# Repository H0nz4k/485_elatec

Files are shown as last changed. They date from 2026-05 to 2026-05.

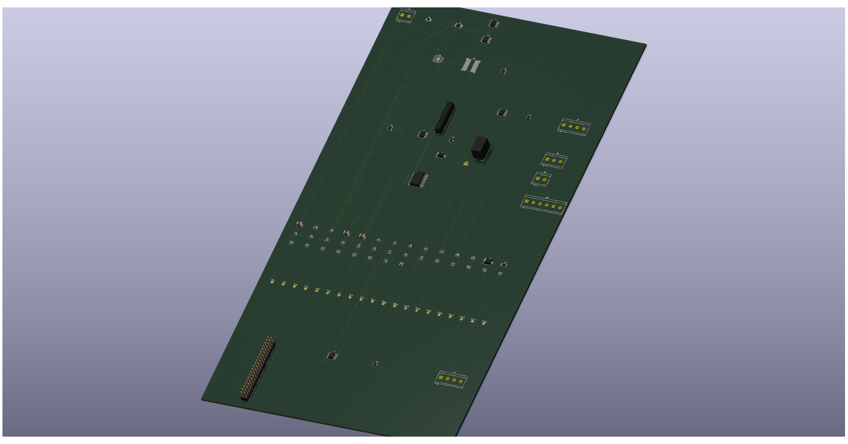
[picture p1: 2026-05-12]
kicad/twn4_access_system/twn4_access_system_rev_c.png

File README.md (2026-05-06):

# 485_elatec

Hardware concept for an ELATEC TWN4 MultiTech 3 BLE carrier board with RS-485 / OSDP, wide-range DC input, door lock outputs, and a Raspberry Pi-side RS-485 gateway.

## Current contents

- `analyza_twn4_carrier.md` - design analysis and architecture notes
- `schema_twn4_carrier_rev_a.md` - first schematic-level design proposal
- `rpi_gateway_hw.md` - Raspberry Pi RS-485 gateway / HAT notes
- `kicad/twn4_access_system/` - KiCad concept schematic for the reader carrier and RPi gateway

The design is currently Rev A concept-level work. It still needs component selection, footprint assignment, detailed ERC review, PCB layout, and bench validation before hardware production.

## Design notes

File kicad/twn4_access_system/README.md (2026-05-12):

# KiCad: TWN4 access system

This is a concept KiCad project for two related hardware blocks:

- reader-side TWN4 carrier / door module
- Raspberry Pi-side RS-485 gateway / HAT

The project contains two schematic sheets:

- `twn4_access_system.kicad_sch` - Rev A concept drawing
- `twn4_access_system_rev_b.kicad_sch` - Rev B schematic draft with concrete symbols, named nets, candidate footprints, and both reader-side and Raspberry Pi-side hardware

The Rev B electrical design notes and preliminary BOM are documented in:

- `../../schema_electrical_rev_b.md`
- `../../bom_rev_b.csv`

Current Rev B KiCad status:

- netlist export works and contains the real schematic components/nets
- Rev B now includes explicit service-prototype passives, RS-485 termination/bias options, lock/relay/input support parts and testpoints
- ERC has no error-severity findings after the current pass
- remaining ERC messages are warnings from embedded one-off symbols and intentionally single-ended configuration nets
- no Rev B PCB has been validated yet

Next KiCad step: replace the embedded placeholder-style symbols with proper library symbols/aliases, lock exact manufacturer footprints, then create the first service PCB layout.

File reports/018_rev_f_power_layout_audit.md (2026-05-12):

# Report 018 - Rev F power layout audit

## What changed

- Created Rev F branch and KiCad files from the Rev E routed checkpoint:
  - `kicad/twn4_access_system/twn4_access_system_rev_f.kicad_sch`
  - `kicad/twn4_access_system/twn4_access_system_rev_f_compact_power_cleanup.kicad_pcb`
- Added Rev F title block metadata and an F.Fab audit note:
  - `REV F AUDIT CHECKPOINT - MANUAL BUCK/LOCK REROUTE REQUIRED`
- Generated Rev F manufacturing draft outputs:
  - `manufacturing/rev_f/gerbers`
  - `manufacturing/rev_f/drill`
  - `manufacturing/rev_f/bom`
  - `manufacturing/rev_f/pick_place`
  - `manufacturing/rev_f/jlcpcb_upload_draft`
- Ran DRC after restoring the DRC-clean Rev E routing baseline with Rev F metadata.

## Why it changed

Rev E was DRC clean, but the critical power nets were still routed with autorouter-style 0.20 mm tracks. Rev F started the power-layout cleanup by testing whether the existing autorouted topology could safely support wider power traces.

## Attempted cleanup

Two widening attempts were tested and rejected:

- aggressive pass:
  - VIN nets: 0.60 mm
  - LOCK_SW_LOW: 0.80 mm
  - +5V: 0.40 mm
  - SW_NODE: 0.60 mm
  - result: 152 DRC violations
- conservative pass:
  - VIN_PROT/+5V/SW_NODE: 0.25 mm
  - result: 38 DRC violations

The violations were mostly clearance errors and some actual shorting-item reports where widened tracks crossed too close to unrelated autorouted logic traces.

## Engineering conclusion

ASSUMPTION: The existing Rev E routing is acceptable as a connectivity proof, but it is not a safe basis for simply widening traces.

The correct Rev F power cleanup is a manual reroute of the buck and lock/relay sections:

- place and route the buck loop as a local power island,
- keep the switching node compact,
- keep feedback away from noisy nodes,
- route lock current paths as short, wide, intentional copper,
- keep relay coil and lock switch paths separated,
- preserve 0.20 mm or larger clearance after the wider copper is in place.

## Verification

Final Rev F checkpoint DRC:

- `reports/rev_f_power_cleanup_drc.rpt`
- 0 DRC violations
- 0 unconnected pads
- 0 footprint errors

## Remaining risks

- Buck layout still needs manual reroute before ordering.
- Lock/relay current paths still need manual reroute before ordering.
- Connector current rating and real lock current remain unverified.
- X2/standoff geometry still requires physical validation.
- Schematic Rev F is still derived from the broader Rev E/Rev B schematic and should be split into carrier-only and RPi-gateway sheets before production.

## Next step

Open the Rev F PCB in KiCad GUI and manually reroute only these blocks:

1. buck input/protection to U2,
2. U2/L1/C5/C6 5 V power loop,
3. lock connector J5 to D2/Q4/VIN_PROT/GND return,
4. relay K1/Q3/D5 coil path.

After manual reroute, rerun DRC and update manufacturing outputs.

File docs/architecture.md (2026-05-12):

# Architecture

## Rev B Prototype Blocks

1. TWN4 carrier interface
2. Protected 12-48 V input
3. 5 V buck supply for TWN4 and local logic
4. Optional/local 3.3 V logic rail
5. RS-485 / OSDP interface
6. Dry relay output
7. Powered lock output
8. Door/REX/tamper/AUX inputs
9. Raspberry Pi RS-485 gateway/HAT concept

## Communication

Primary wired communication for Rev B is OSDP over half-duplex RS-485.

BLE is intentionally not part of the first production prototype. It remains a future feature because the first board must validate power, COM1 polarity, RS-485 and door IO first.

## Service Prototype Philosophy

The first board should be easy to measure and rework:

- large testpoints,
- jumpers for RS-485 termination and bias,
- service disconnect for lock output,
- clearly labeled field terminals,
- conservative trace widths and clearances.

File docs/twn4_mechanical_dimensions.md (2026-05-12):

# TWN4 MultiTech 3 BLE Mechanical Notes

Source: `TWN4DevPack507.zip`, extracted document `_extracted_docs/TWN4 MultiTech 3 DocRev10.pdf`, sections 2.2 and 2.3.2.

## Extracted Dimensions

- Reader PCB envelope: 50.00 mm x 35.00 mm.
- Figure 2.3 top view also shows reference dimensions 12.50 mm, 10.00 mm, 16.50 mm, 11.20 mm, 20.00 mm, and 2.80 mm around component and mounting geometry.
- Figure 2.3 bottom view shows additional reference dimensions 22.80 mm, 8.00 mm, and USB connector offset 4.00 mm.
- X2 generic interface:
  - double row header/socket,
  - 2.00 mm pitch,
  - 2 x 12 positions,
  - example populated connector: Samtec `PTT-124-01-S-D`,
  - pin orientation shown in Figure 2.5, with pin 1/2 at one end and pin 23/24 at the opposite end.

## Rev D Layout Assumptions

- ASSUMPTION: The compact carrier should use the TWN4 50.00 mm x 35.00 mm body as the primary mechanical envelope.
- ASSUMPTION: The reader should plug into the carrier through X2; the carrier PCB may extend to one side/bottom for field wiring.
- ASSUMPTION: The RPi gateway electronics are not part of this compact reader carrier. They should become a separate PCB or separate schematic variant.
- ASSUMPTION: Current 5.08 mm terminal blocks are too large for a carrier only slightly bigger than the reader. Rev D keeps them as workflow placeholders, but a real compact layout should move to smaller pluggable connectors, likely 3.50 mm or 2.50/2.54 mm depending on current and installer ergonomics.

## Open Mechanical Risks

- The exact X2 pin-1 center coordinate relative to the 50 x 35 mm TWN4 body still needs physical confirmation against a real reader, a printed 1:1 drawing, or an original mechanical CAD/DXF if ELATEC provides one.
- Connector mating height is not yet fixed. A carrier socket/pin solution must be chosen before production.
- Mounting hole/standoff geometry is not yet implemented in PCB.
- Component height under the reader body is not validated. Keep tall components in the side/bottom extension unless the reader standoff height is known.

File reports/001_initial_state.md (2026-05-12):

# 001 Initial State

Date: 2026-05-07

## What Was Checked

- Workspace root: `C:\Work\projects\elatec-485`
- KiCad project: `kicad/twn4_access_system/twn4_access_system.kicad_pro`
- Rev A concept schematic: `kicad/twn4_access_system/twn4_access_system.kicad_sch`
- Rev B schematic draft: `kicad/twn4_access_system/twn4_access_system_rev_b.kicad_sch`
- Existing design notes: `schema_electrical_rev_b.md`, `bom_rev_b.csv`, `rpi_gateway_hw.md`
- KiCad CLI version: 9.0.7

## Toolchain State

- `git.exe` is not available in this local environment.
- The workspace is not a local git checkout; `.git` is missing.
- Required branch `feature/rev-b-jlcpcb-prototype` could not be created locally.

ASSUMPTION: work continues in this filesystem copy, and the resulting files will be copied or committed later from a real git clone.

## Current KiCad State

- Rev B schematic exports a KiCad netlist.
- Rev B schematic currently uses embedded one-off symbols for several project-specific parts.
- A local symbol library file was generated as `kicad/twn4_access_system/rev_b_symbols.kicad_sym`, but CLI netlist export was more reliable with embedded symbols, so the active schematic still uses embedded symbols for now.
- No routed PCB file exists yet for Rev B.

## Verification

- KiCad CLI is available.
- Rev B netlist export was run successfully after cleanup.
- ERC was run with KiCad CLI.

## Risks

- No git branch or commits can be made until the project is opened in a real git clone with git installed.
- Rev B is not ready for JLCPCB order because there is no validated PCB layout.
- Mechanical connector alignment for TWN4 X2 is not verified.

## Next Step

Continue with schematic cleanup, footprint checks, report generation, and prototype manufacturing documentation.

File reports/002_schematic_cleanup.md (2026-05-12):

# 002 Schematic Cleanup

Date: 2026-05-07

## What Changed

- Updated Rev B schematic footprint candidates where KiCad 9 had direct matching library footprints.
- Generated a local project symbol library: `kicad/twn4_access_system/rev_b_symbols.kicad_sym`.
- Generated a project symbol library table: `kicad/twn4_access_system/sym-lib-table`.
- Kept the active Rev B schematic on embedded symbols because KiCad CLI netlist export remained correct in that mode.
- Exported a KiCad BOM to `manufacturing/rev_b/bom/rev_b_kicad_bom.csv`.
- Added explicit service-prototype support parts: input capacitors, input TVS placeholder, LTC4367 divider placeholders, LM5164 feedback/RON/bootstrap/output parts, RS-485 termination/bias options, lock and relay gate/pulldown/flyback parts, input pull/filter parts and testpoints.

## Why

The previous Rev B schematic had usable named nets but was still a generated draft. The cleanup step makes it more reviewable and starts separating reusable project assets from one-off generation.

## Assumptions

- Embedded symbols are acceptable for the current prototype checkpoint because they preserve the full netlist.
- The local symbol library will be used in a later GUI cleanup pass or regenerated into a fully linked KiCad library once netlist behavior is confirmed.
- Footprints remain provisional until exact orderable manufacturer part numbers are locked.

## Verified

- Netlist export: OK
- Netlist component count: 82
- Net count: 53
- ERC errors: 0
- ERC warnings: 135

## Remaining ERC Warnings

The remaining warnings are not electrical pin-connect errors. They are mostly:

- embedded/project symbol library warnings,
- intentionally single-ended setup/configuration nets,
- intentionally DNP jumper/bias/termination options.

## Risks

- Some symbols are simplified functional symbols, not final manufacturer symbols.
- Some support values are still engineering placeholders and must be reviewed against final part numbers and measured current needs.
- A PCB generated from this exact schematic would still need a senior review before fabrication.

## Next Step

Add explicit support components and testpoints into the schematic, then create the first service-oriented PCB layout.

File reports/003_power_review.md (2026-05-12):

# 003 Power Review

Date: 2026-05-07

## Design Intent

Input range target: 12 V to 48 V nominal.

The Rev B concept uses:

- protected input rail `VIN_PROT`,
- 5 V buck rail for TWN4 and relay/logic support,
- optional/local 3.3 V rail for IO expansion if needed.

## Candidate Parts

- Input protection controller: LTC4367
- Buck regulator: LM5164
- 3.3 V LDO: TLV75533

## Source Checks

- TI LM5164 product page confirms 6 V to 100 V input capability and 1 A max output class: https://www.ti.com/product/LM5164
- Analog Devices LTC4367 product page confirms 2.5 V to 60 V operating range, overvoltage protection to 100 V, reverse supply protection, and control of back-to-back N-MOSFETs: https://www.analog.com/en/products/ltc4367.html

## Assumptions

- TWN4 plus local electronics stay below roughly 500 mA on 5 V in normal operation.
- Door lock power is not taken from the 5 V rail; it is switched from protected input voltage.
- First prototype is service/debug oriented, so efficiency and board size are secondary to robust measurement and rework.

## Schematic Additions Made

- Added input bulk/HF capacitors.
- Added input TVS placeholder.
- Added LTC4367 UV/OV divider placeholders.
- Added LM5164 RON, feedback divider, bootstrap capacitor, input capacitor and output capacitors.
- Added 3.3 V LDO input/output capacitors.
- Added power testpoints.

## Still Required

- Final input TVS part number for 48 V nominal environment.
- Final LTC4367 divider calculation.
- Final LM5164 values checked against the exact switching target and load.
- Thermal/current review after exact lock and reader current are known.

## Risks

- 48 V nominal systems can have transients above nominal; TVS selection must not clamp during normal operation but must protect downstream parts.
- LM5164 layout is critical. The high di/dt loop must be compact, with SW node kept small.
- Lock transients can inject noise into VIN_PROT if flyback/TVS placement is poor.

## Next Step

Add explicit power passives and testpoints before PCB layout.

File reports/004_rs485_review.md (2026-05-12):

# 004 RS-485 Review

Date: 2026-05-07

## Design Intent

Use RS-485 for OSDP as the first wired multi-reader path. BLE is deferred to a future revision.

## Candidate Parts

- Reader side transceiver: THVD1450
- RPi side transceiver: THVD1450
- RS-485 TVS: SM712

## Source Checks

- TI THVD1450 product page describes 3.3 V to 5 V RS-485 family with high IEC ESD protection: https://www.ti.com/product/THVD1450
- Bourns SM712 datasheet identifies the device as RS-485 port protection: https://www.bourns.com/docs/product-datasheets/cdsot23-sm712.pdf

## Assumptions

- OSDP is half-duplex RS-485.
- `DE` and `RE#` are tied to one direction-control signal for the first prototype.
- Bias and termination must be selectable so only the bus end is terminated/biased.

## Schematic Additions Made

- Added DNP 120 ohm termination option.
- Added DNP 680 ohm pull-up/pull-down bias options.
- Added A/B series resistor options.
- Added RS-485 and UART-related testpoints.

## Still Required

- Decide final jumper/DIP implementation for termination and bias.
- Verify A/B polarity on bench and silkscreen.
- Add PCB placement so TVS is physically close to field connector.

## Galvanic Isolation Decision

Recommendation for Rev B: do not add isolation yet unless field wiring length, ground potential differences, or external PSU topology demand it.

Reason: first prototype should validate TWN4 COM1 polarity, OSDP timing, bus bias/termination and power/lock behavior with fewer variables. Add isolation in Rev C after bench and site conditions are known.

## Risks

- A/B naming varies by vendor. The prototype must expose testpoints and clear silkscreen so polarity can be swapped or corrected if needed.
- TWN4 COM1 is documented as low-active TTL; polarity must be checked on an oscilloscope with firmware before final PCB release.

## Next Step

Make termination and bias explicit in schematic and PCB, with accessible jumpers.

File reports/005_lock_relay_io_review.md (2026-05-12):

# 005 Lock Relay IO Review

Date: 2026-05-07

## Design Intent

Rev B should support:

- dry relay contact for external door controller input,
- powered lock output from protected input rail,
- door/REX/tamper/AUX inputs for field wiring.

## Assumptions

- Lock current is unknown, so the first prototype must be conservative and serviceable.
- Powered lock output should be switchable from `VIN_PROT`, not from 5 V.
- Relay output is a dry contact only.

## Schematic Additions Made

- Added lock service link.
- Added lock gate resistor and pulldown.
- Added relay gate resistor and pulldown.
- Added relay flyback diode.
- Added input pull-up and RC filter placeholders.
- Added testpoints for lock, relay and inputs.

## Still Required

- Select final lock flyback/TVS strategy after lock type and current are known.
- Add explicit ESD/TVS input arrays near input connector.
- Confirm MOSFET current/thermal margin against target lock.

## Risks

- Door strikes and maglocks can have very different transient behavior.
- If the lock shares supply wiring with logic, poor return routing can reset TWN4 or corrupt RS-485.
- Long input cables need ESD and filtering close to the connector.

## Next Step

Promote these support parts from notes into real schematic components and keep the lock power path physically away from logic on PCB.

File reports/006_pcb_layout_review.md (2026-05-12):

# 006 PCB Layout Review

Date: 2026-05-07

## Current State

No Rev B PCB layout has been produced or validated yet.

## Layout Requirements

- Service prototype, not miniaturized.
- Large testpoints.
- Clear connector labels.
- Buck regulator placed and routed according to datasheet layout guidance.
- Input protection close to power connector.
- RS-485 TVS close to bus connector.
- Lock transient suppression close to lock connector.
- Logic and lock current returns controlled deliberately.
- Optional jumpers for RS-485 termination and bias.

## Manufacturing Assumptions

- JLCPCB standard 2-layer or 4-layer process can be used.
- For first prototype, 4-layer is preferred if cost is acceptable because it gives a cleaner ground reference for buck, RS-485 and logic.
- Use conservative clearances and trace widths, especially for VIN and lock current.

## Risks

- Mechanical X2 position is not locked.
- Connector height and standoff height are not locked.
- Current draw of selected lock is unknown.

## Next Step

Create the initial PCB only after schematic support components and footprints are explicit enough for DRC and BOM/CPL consistency.

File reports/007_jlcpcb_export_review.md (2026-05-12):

# 007 JLCPCB Export Review

Date: 2026-05-07

## Current State

The manufacturing directory exists, but it is not yet a complete order package.

Generated:

- `manufacturing/rev_b/bom/rev_b_kicad_bom.csv`

Not generated yet:

- Gerbers
- Drill files
- Pick and Place / CPL

## Reason

There is currently no validated Rev B PCB layout file. Generating manufacturing outputs without a reviewed PCB would create false confidence.

## JLCPCB Requirements To Satisfy

- Valid Gerber set.
- Valid drill files.
- BOM with exact manufacturer/orderable parts.
- CPL/Pick and Place matching footprints and reference designators.
- Assembly notes identifying hand-soldered parts.
- Known risks documented.

## Risks

- Candidate footprints are not the same as confirmed JLCPCB-available parts.
- Some high-voltage/input-protection parts may need manual assembly.
- TWN4 mating connector may be hand-assembled unless a reliable JLCPCB-available equivalent is selected.

## Next Step

Finish schematic support components, create PCB, run DRC, then export manufacturing files.

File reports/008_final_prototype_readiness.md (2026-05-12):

# 008 Final Prototype Readiness

Date: 2026-05-07

## Readiness Decision

Current status: NOT READY TO ORDER.

## Why

The electrical concept and Rev B schematic draft are useful, but a production-orderable prototype still requires:

- explicit support passives in schematic,
- final footprints,
- PCB layout,
- DRC,
- Gerber/drill export,
- CPL export,
- final BOM review,
- visual Gerber review.

## What Is Ready

- Project structure.
- Rev B schematic draft with named nets.
- KiCad BOM export.
- Reports and manufacturing documentation scaffold.
- Source-backed component direction for power, RS-485, IO expander and input protection.

## Blocking Items

- No validated PCB.
- No exact mechanical X2 placement.
- No final lock current target.
- No final JLCPCB/LCSC part mapping.
- Git branch and commits cannot be created in this local workspace because git is unavailable and `.git` is missing.

## Recommendation

Continue with schematic completion before PCB. Do not order hardware from the current state.

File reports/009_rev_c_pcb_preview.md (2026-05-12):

# 009 Rev C PCB Preview

Date: 2026-05-07

## What Changed

- Created `kicad/twn4_access_system/twn4_access_system_rev_c.kicad_pcb`.
- Rev C PCB is generated from the Rev B schematic netlist/BOM.
- Added a service-style board outline and placed all 82 schematic components as physical footprints.
- Added engineering-preview silkscreen warnings directly on PCB.

## Why

Rev B was blocked because it had no PCB, no DRC, no Gerbers, no drill files and no CPL. Rev C starts filling those gaps while keeping the manufacturing risk visible.

## Assumptions

ASSUMPTION: Rev C is an engineering preview, not an orderable routed prototype.

ASSUMPTION: Footprints are good enough for first KiCad export validation, but not final enough for purchase or assembly without human review.

ASSUMPTION: Mechanical TWN4 X2 placement is still unknown, so the PCB cannot be treated as mechanically validated.

## Verified

- KiCad PCB file loads through KiCad CLI.
- DRC runs.
- Gerber export runs.
- Drill export runs.
- Position/CPL export runs.
- PDF preview export runs.

## DRC Result

- DRC violations: 9
- Unconnected pads/items: 164

The current DRC violations are silkscreen warnings/overlaps and unrouted connections. There are no remaining clearance/courtyard collisions after moving the Raspberry Pi section.

## Risks

- The board is placed but not routed.
- DRC is not clean.
- Schematic parity has not been passed.
- Gerbers exist, but must not be ordered.
- CPL exists, but placement has not been manually reviewed.

## Next Step

Route the PCB deliberately by functional block:

1. Power input/protection/buck.
2. TWN4 X2 and 5 V/GND.
3. RS-485 transceiver, TVS, termination and bias.
4. Lock output current path.
5. Relay and IO.
6. Raspberry Pi gateway section.

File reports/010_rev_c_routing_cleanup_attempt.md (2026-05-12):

# 010 Rev C Routing Cleanup Attempt

Date: 2026-05-07

## What Was Tried

An automated routing pass was attempted directly in the KiCad PCB file:

- parsed footprint pad coordinates,
- grouped pads by net,
- added vias at pad locations,
- added coarse bottom-layer trunk routes per net,
- ran DRC as `rev_c_drc_routing_pass1.rpt`.

## Result

The pass reduced unrouted items to zero, but created unacceptable electrical/layout errors:

- DRC violations: 638
- Unconnected items: 0
- Main failure types: track crossings, shorts between nets, clearance issues.

## Root Cause

The simple routing algorithm used net channels and vertical drops on one copper layer. It had no obstacle avoidance, no layer-pair strategy, no real maze routing and no current-aware routing. It therefore connected the ratsnest but produced invalid copper.

## Cleanup Performed

The bad autoroute tracks and vias were removed.

The large warning silkscreen text that caused DRC warnings was removed from the PCB and preserved in documentation instead.

After cleanup:

- DRC violations: 0
- Unconnected items: 164

Report: `reports/rev_c_drc_cleanup_pass1.rpt`

## Decision

Do not keep the automatic routing copper. A board with 638 DRC violations is worse than an unrouted board.

The current Rev C PCB is therefore intentionally left placed-but-unrouted, with clean geometry DRC and explicit unrouted state.

## Next Step

Routing must proceed block by block:

1. Power input, protection and buck.
2. TWN4 X2 power/GND and COM1.
3. RS-485 transceiver, TVS, termination and bias.
4. Lock output current path.
5. Relay and inputs.
6. Raspberry Pi gateway section.

For real autorouting, export through KiCad GUI/Specctra DSN or use an installed router. KiCad CLI in this environment does not expose DSN export and Java/freerouting is not installed.

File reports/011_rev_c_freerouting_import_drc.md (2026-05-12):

# 011 Rev C Freerouting Import and DRC

Date: 2026-05-08

## What Changed

- Exported Specctra DSN from KiCad GUI to `manufacturing/rev_c/twn4_rev_c.dsn`.
- Routed the DSN with Freerouting 2.2.3 using Java 25.
- Imported the resulting SES back into KiCad GUI.
- Saved the routed PCB as `kicad/twn4_access_system/twn4_access_system_rev_c.kicad_pcb`.
- Regenerated Rev C Gerbers, drill, CPL and PDF preview.

## Freerouting Result

Input:

- `manufacturing/rev_c/twn4_rev_c.dsn`

Output:

- `manufacturing/rev_c/twn4_rev_c.ses`
- `manufacturing/rev_c/freerouting_pass1.log`

Freerouting log summary:

- Started with 164 unrouted connections.
- Pass 1: 46 unrouted.
- Pass 2: 18 unrouted.
- Pass 3: 3 unrouted.
- Pass 4: no unrouted reported.
- Session completed in 34.73 seconds.

## KiCad DRC Result After Import

Report:

- `reports/rev_c_drc_after_freerouting.rpt`

Result:

- DRC violations: 0
- Unconnected pads: 0
- Footprint errors: 0

PCB statistics:

- Segments: 708
- Vias: 105

## Manufacturing Outputs Updated

- `manufacturing/rev_c/gerbers/`
- `manufacturing/rev_c/drill/`
- `manufacturing/rev_c/pick_place/rev_c_cpl.csv`
- `manufacturing/rev_c/rev_c_preview.pdf`

## Engineering Caveat

DRC-clean autorouted copper is not the same as a reviewed power/EMC layout.

This Rev C route is suitable as a routing feasibility milestone, but it still needs manual review before ordering:

- buck high-current/high-dVdt loop,
- lock current path and return,
- RS-485 TVS placement and A/B path,
- creepage/clearance expectations for 48 V and transients,
- connector orientation and TWN4 X2 mechanical alignment,
- BOM and CPL orientation review.

## Decision

Rev C is now routed and DRC-clean in KiCad. It is closer to an orderable prototype, but the recommendation remains: do a visual/manual engineering review before submitting to JLCPCB.

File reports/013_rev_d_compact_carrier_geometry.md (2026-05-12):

# 013 Rev D Compact Carrier Geometry

## What Changed

- Created `kicad/twn4_access_system/twn4_access_system_rev_d_compact_carrier.kicad_pcb`.
- Added a compact working board outline of 110 mm x 70 mm.
- Added a 50 mm x 35 mm TWN4 reference envelope on the fabrication layer.
- Positioned X2 as the primary reader mating reference.
- Removed the RPi gateway footprints from this compact carrier PCB variant because the RPi side should be a separate hardware module.
- Exported a visual preview to `manufacturing/rev_d/rev_d_compact_carrier_preview.pdf` and `manufacturing/rev_d/rev_d_compact_carrier_preview.png`.

## Why It Changed

The previous Rev C routed board proved that KiCad -> DSN -> Freerouting -> SES -> KiCad works, but it was physically too large and not aligned with the intended product shape. Rev D starts a compact carrier direction: reader body first, field wiring in a controlled extension.

## Assumptions

- ASSUMPTION: TWN4 MultiTech 3 BLE body envelope is 50.00 mm x 35.00 mm from ELATEC Figure 2.3.
- ASSUMPTION: X2 uses a 2 x 12, 2.00 mm pitch mating connector based on ELATEC Figure 2.5 and Samtec `PTT-124-01-S-D`.
- ASSUMPTION: For compact Rev D, RPi gateway hardware is separate from the reader carrier.
- ASSUMPTION: The existing 5.08 mm terminal block footprints are placeholders for compact layout exploration. A production compact carrier likely needs smaller field connectors.

## Verified

- KiCad 9.0.7 can load the Rev D PCB file.
- KiCad CLI can export the Rev D preview PDF and PNG.
- ELATEC mechanical page renderings were generated under `docs/mechanical_extract/`.

## DRC Result

- DRC report: `reports/rev_d_compact_carrier_drc.rpt`.
- Manufacturing-side copy: `manufacturing/rev_d/rev_d_compact_carrier_drc.rpt`.
- Superseded by report 014 after placement cleanup.
- Original first-pass result: 77 violations, including placement/courtyard/clearance issues and unconnected items.
- Updated result after report 014: no hard shorting placement violations; remaining blockers are unrouted nets and non-critical silkscreen/library warnings.

## Remaining Risks

- X2 placement must be verified physically before any PCB order.
- The current 5.08 mm terminal blocks consume too much board edge for the desired compact form factor.
- Relay, lock output, and power input spacing still need a real manufacturable arrangement.
- No routing has been done for Rev D.
- No Gerber/Drill/CPL manufacturing package should be generated from this Rev D placement yet.

## Next Step

- Decide whether Rev D keeps 5.08 mm field terminals and grows slightly, or switches to smaller pluggable terminal blocks.
- Confirm X2 coordinate and mating height.
- Replace placeholder compact placement with a routed board floorplan:
  - X2 and reader keepout fixed first,
  - power input and buck in one corner,
  - RS-485 connector/protection together at the edge,
  - lock/relay output separated from logic,
  - inputs on a low-current connector group.

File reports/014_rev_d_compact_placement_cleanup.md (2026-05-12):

# 014 Rev D Compact Placement Cleanup

## What Changed

- Continued compact Rev D placement cleanup in `kicad/twn4_access_system/twn4_access_system_rev_d_compact_carrier.kicad_pcb`.
- Increased the working board outline from 110 mm x 70 mm to 116 mm x 88 mm.
- Moved power protection, buck support parts, RS-485 connector area, relay/lock protection parts, and field connectors to remove hard pad collisions.
- Updated preview exports:
  - `manufacturing/rev_d/rev_d_compact_carrier_preview.pdf`
  - `manufacturing/rev_d/rev_d_compact_carrier_preview.png`
- Copied the updated DRC report into `manufacturing/rev_d/rev_d_compact_carrier_drc.rpt`.

## Why It Changed

The first Rev D compact geometry pass still had physical shorts and courtyard overlaps caused by using large 5.08 mm terminal blocks and placeholder production footprints in a compact carrier. This pass focused on making the placement electrically non-destructive before attempting routing.

## Assumptions

- ASSUMPTION: Rev D remains a placement/routing exploration, not a production release.
- ASSUMPTION: Keeping the current 5.08 mm terminal blocks is acceptable for this intermediate pass, even though they make the board larger than the final desired compact carrier.
- ASSUMPTION: Final compact hardware should evaluate smaller field connectors before committing to PCB manufacturing.

## Verified

- KiCad 9.0.7 can load the updated Rev D PCB.
- KiCad CLI DRC runs successfully.
- KiCad CLI PDF export runs successfully.
- Preview PNG was regenerated from the exported PDF.

## DRC Result

- DRC report: `reports/rev_d_compact_carrier_drc.rpt`.
- Current result: 12 non-unconnected DRC items plus 142 unconnected pads.
- Critical placement shorts are cleared:
  - `shorting_items`: 0
  - remaining non-routing items are silkscreen warnings and library footprint mismatch warnings.
- The board is still unrouted.

## Remaining Risks

- Rev D is not ready for manufacturing.
- The current outline is 116 mm x 88 mm, which is still larger than the desired final compact product direction.
- Large field terminal footprints dominate the board size.
- X2 mechanical position and connector mating height still require physical verification.
- DSN export for Freerouting requires KiCad GUI because KiCad CLI 9.0.7 does not expose a Specctra DSN export command.

## Next Step

- In KiCad GUI, export Rev D as Specctra DSN:
  - open `twn4_access_system_rev_d_compact_carrier.kicad_pcb`,
  - use `Soubor -> Export -> Specctra DSN`,
  - save to `manufacturing/rev_d/twn4_rev_d_compact.dsn`.
- Run Freerouting against that DSN and import the resulting SES.
- After routing, run DRC again and decide whether the large terminal block strategy is acceptable or whether Rev E should switch to smaller connectors.

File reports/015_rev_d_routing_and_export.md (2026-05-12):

# 015 Rev D Routing And Export

## What Changed

- Exported Rev D Specctra DSN using KiCad Python API:
  - `manufacturing/rev_d/twn4_rev_d_compact.dsn`
- Routed the compact Rev D placement with Freerouting 2.2.3:
  - `manufacturing/rev_d/twn4_rev_d_compact.ses`
  - `manufacturing/rev_d/freerouting_rev_d.log`
- Imported the routed SES into a new PCB file:
  - `kicad/twn4_access_system/twn4_access_system_rev_d_compact_routed.kicad_pcb`
- Exported routed preview:
  - `manufacturing/rev_d/rev_d_compact_routed_preview.pdf`
- Exported manufacturing workflow files:
  - Gerbers: `manufacturing/rev_d/gerbers/`
  - Filtered JLCPCB draft upload set: `manufacturing/rev_d/jlcpcb_upload_draft/`
  - Drill: `manufacturing/rev_d/drill/`
  - CPL: `manufacturing/rev_d/pick_place/rev_d_cpl.csv`
  - BOM: `manufacturing/rev_d/bom/rev_d_kicad_bom.csv`

## Why It Changed

Rev D needed proof that the compact carrier placement could actually be routed. The previous Rev C proved the routing workflow on an oversized board; this pass proves the same flow on a compact reader-carrier direction.

## Assumptions

- ASSUMPTION: Freerouting output is acceptable as a routing feasibility check, not as final power/buck/EMC-quality routing.
- ASSUMPTION: The current 5.08 mm terminals are temporary workflow placeholders and may be replaced by smaller connectors in a later mechanical/product pass.
- ASSUMPTION: Rev D excludes the RPi gateway electronics; those belong on a separate board.

## Verified

- Freerouting started with 142 unrouted connections and completed with final score 976.50.
- KiCad imported the SES successfully.
- KiCad DRC after routing:
  - 0 unconnected pads,
  - 0 footprint errors,
  - no copper clearance or shorting errors after board-edge adjustment.
- Remaining DRC items are warnings only:
  - 2 terminal block library footprint mismatch warnings,
  - 2 silkscreen-over-copper warnings.

## DRC Result

- Routed DRC report: `reports/rev_d_compact_routed_drc.rpt`.
- Current routed result: 4 warnings, 0 unconnected pads.

## Remaining Risks

- Rev D is not approved for ordering yet.
- Buck converter routing needs manual review and likely manual reroute before a real PCB order.
- Power/lock current trace widths need review against target lock current.
- RS-485 A/B polarity and OSDP behavior still need bench validation.
- X2 exact position and connector height still need physical validation.
- Gerbers currently include extra documentation layers from the default export; JLCPCB upload should use only copper, mask, paste, silkscreen, edge cuts, and drill files.

## Next Step

- Open routed Rev D in KiCad 3D/PCB viewer and visually inspect:
  - X2 reader envelope alignment,
  - field connector accessibility,
  - buck loop routing,
  - lock/relay trace widths,
  - RS-485 protection location.
- For a true orderable compact board, create the next revision with final field connectors and a manual power/RS-485/lock layout.

## Follow-up

Report 016 repeats the routing pass using the DSN exported from KiCad GUI and stores the result as `twn4_access_system_rev_d_compact_gui_routed.kicad_pcb`.

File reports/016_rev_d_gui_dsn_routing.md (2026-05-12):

# 016 Rev D GUI DSN Routing

## What Changed

- Used the GUI-exported DSN provided at `manufacturing/rev_d/twn4_rev_d_compact.dsn`.
- Routed it with Freerouting 2.2.3 and saved:
  - `manufacturing/rev_d/twn4_rev_d_compact_gui_export.ses`
  - `manufacturing/rev_d/freerouting_rev_d_gui_export.log`
- Imported the SES into a separate KiCad PCB file:
  - `kicad/twn4_access_system/twn4_access_system_rev_d_compact_gui_routed.kicad_pcb`
- Adjusted the routed board outline to clear one autorouter via near the top board edge.
- Exported preview:
  - `manufacturing/rev_d/rev_d_compact_gui_routed_preview.pdf`
  - `manufacturing/rev_d/rev_d_compact_gui_routed_preview.png`

## Why It Changed

This validates the same routing workflow using the DSN exported from KiCad GUI rather than only the DSN generated through KiCad Python API.

## Verified

- Freerouting started with 142 unrouted nets and completed with final score 976.50.
- SES import into KiCad succeeded.
- DRC after board-edge adjustment:
  - 0 unconnected pads,
  - 0 footprint errors,
  - no copper clearance errors,
  - no shorting errors.

## DRC Result

- DRC report: `reports/rev_d_compact_gui_routed_drc.rpt`.
- Remaining DRC items: 4 warnings.
  - 2 terminal-block footprint library mismatch warnings.
  - 2 silkscreen-over-copper warnings.

## Remaining Risks

- This is still a routed workflow prototype, not an order-approved board.
- Buck converter routing and lock-current paths need manual engineering review.
- X2 mechanical alignment and connector height must be verified physically.
- Field connectors remain large 5.08 mm placeholders and should be revisited for a compact Rev E.

## Next Step

- Use `twn4_access_system_rev_d_compact_gui_routed.kicad_pcb` as the routed reference generated from GUI DSN.
- If continuing toward manufacturing, manually review and reroute:
  - power input protection,
  - buck loop,
  - lock output current path,
  - RS-485 A/B and protection section.

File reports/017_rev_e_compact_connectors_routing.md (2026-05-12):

# Report 017 - Rev E compact connectors and routing

## What changed

- Created Rev E compact carrier PCB variant:
  - `kicad/twn4_access_system/twn4_access_system_rev_e_compact_carrier.kicad_pcb`
  - `kicad/twn4_access_system/twn4_access_system_rev_e_compact_routed.kicad_pcb`
- Created Rev E schematic copy:
  - `kicad/twn4_access_system/twn4_access_system_rev_e.kicad_sch`
- Replaced large 5.08 mm field terminal footprints with smaller 3.50 mm Phoenix PT-1,5 style terminal blocks.
- Kept RPi gateway out of the compact carrier PCB. RPi gateway is treated as a separate board path.
- Routed Rev E through Specctra/Freerouting workflow:
  - DSN: `manufacturing/rev_e/twn4_rev_e_compact.dsn`
  - SES: `manufacturing/rev_e/twn4_rev_e_compact.ses`
  - log: `manufacturing/rev_e/freerouting_rev_e.log`
- Expanded final outline to approximately 102 mm x 72 mm to clear silkscreen/edge spacing.
- Exported Gerber, drill, BOM, CPL, and preview files under `manufacturing/rev_e`.

## Why it changed

Rev D proved the compact carrier direction but was still too bulky around the external connectors. Rev E moves toward a more realistic service prototype by using smaller field connectors and a compact board envelope while keeping enough area for measurement, inspection, and first bring-up.

## Assumptions

- ASSUMPTION: 3.50 mm pitch Phoenix PT-1,5 style connectors are acceptable for the first service prototype field wiring.
- ASSUMPTION: lock current is not yet finalized, so the lock connector and copper paths are not order-approved until the actual lock load is known.
- ASSUMPTION: 102 mm x 72 mm is acceptable for Rev E as a compact engineering carrier. It is still not the final mechanical product outline.
- ASSUMPTION: RPi gateway should be separated into its own board instead of being physically mixed with the TWN4 carrier.
- ASSUMPTION: X2 location is based on available ELATEC mechanical documentation and still requires physical validation against the actual reader.

## Verification

- Freerouting completed from 142 unrouted nets to 0 unrouted nets.
- Final KiCad DRC report:
  - `reports/rev_e_compact_routed_drc.rpt`
  - 0 DRC violations
  - 0 unconnected pads
  - 0 footprint errors
- Manufacturing draft outputs exist:
  - `manufacturing/rev_e/gerbers`
  - `manufacturing/rev_e/drill`
  - `manufacturing/rev_e/bom`
  - `manufacturing/rev_e/pick_place`
  - `manufacturing/rev_e/jlcpcb_upload_draft`

## Remaining risks

- Buck converter routing is still autorouter-derived and needs manual review/reroute around input capacitor, switching node, diode/inductor, feedback, and output capacitor.
- Lock/relay high-current paths are routed but not yet manually current-reviewed against the real lock current.
- X2 connector and standoff geometry are not physically verified.
- Schematic Rev E is still derived from broader Rev B content; compact carrier PCB intentionally excludes RPi gateway footprints. A dedicated carrier-only schematic split is recommended before production.
- BOM is a KiCad export, not yet an LCSC/JLCPCB sourced assembly BOM.
- The JLCPCB package is a draft output, not an order-approved release.

## Next step

The next engineering step should be a manual Rev E cleanup pass:

- manually reroute buck power loop,
- manually reroute lock/relay current paths,
- review field connector current ratings,
- split compact carrier schematic from RPi gateway schematic,
- verify X2/standoff coordinates on a printed 1:1 paper or test PCB,
- then rerun DRC and regenerate manufacturing output.

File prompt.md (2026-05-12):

Jsi seniorní elektro inženýr, KiCad specialista, embedded hardware designer, reviewer výrobních podkladů pro JLCPCB a technický root-cause analytik.

Pracuji na elektro projektu, jehož cíl už znáš z předchozí komunikace: vytvořit výrobně použitelný prototyp PCB kolem ELATEC TWN4 čtečky / carrier desky, napájení, RS-485 komunikace, zámku, relé a vstupů. Mechanickou konstrukci teď NEŘEŠ jako samostatný návrh. Mechanické body pouze eviduj jako rizika, požadavky a TODO, pokud brání správnému návrhu PCB.

Tvým cílem je pokračovat dál bez čekání na moje potvrzení až do fáze prototypu připraveného pro výrobu, ideálně importovatelného do JLCPCB.

DŮLEŽITÉ ZÁSADY:
- Pracuj samostatně a neptej se mě na potvrzení běžných kroků.
- Pokud narazíš na nejasnost, udělej kvalifikovaný technický předpoklad, zapiš ho do reportu a pokračuj.
- Zastav se pouze v případě, že by další krok mohl nevratně poškodit projekt, smazat data, změnit main/master větev, nebo vytvořit výrobní podklady s kritickou neověřenou chybou.
- Nezasahuj přímo do aktuálně funkční větve.
- Vždy vytvoř novou git větev pro tuto práci.
- Pracuj jako senior elektro inženýr: ověřuj polaritu, proudy, ochrany, hodnoty pasivů, footprinty, výrobní limity, ERC/DRC a konzistenci schéma ↔ PCB ↔ BOM.
- Cílem není jen „něco nakreslit“, ale připravit smysluplný servisní prototyp, který půjde objednat, osadit, měřit a ladit.

ZAČNI TAKTO:
1. Prozkoumej aktuální stav repozitáře.
2. Identifikuj KiCad projekt, aktuální Rev B schéma, knihovny, footprinty, případné pracovní/vložené symboly a dosavadní poznámky.
3. Vytvoř novou větev, například:
   feature/rev-b-jlcpcb-prototype
4. Zapiš úvodní stav do reportu.
5. Pokračuj samostatně v práci.

HLAVNÍ CÍL PROTOTYPU:
Připravit Rev B elektro návrh carrier PCB pro:
- ELATEC TWN4 čtečku,
- napájení vstupem přibližně 12–48 V,
- stabilní 5 V větev pro TWN4,
- případně 3V3 větev, pokud je potřeba pro logiku,
- RS-485 komunikaci pro OSDP,
- řízení zámku,
- relé výstup,
- vstupy,
- ochrany proti přepětí, přepólování, ESD a špičkám z dlouhých kabelů,
- servisní měření a ladění prvního prototypu.

PRACOVNÍ KROKY:

1. Vyčistit Rev B schéma v KiCadu
- Převést pracovní/vložené symboly na normální KiCad/library symboly.
- Zkontrolovat a sjednotit knihovny.
- Doplnit konkrétní hodnoty odporů, kondenzátorů, cívek, diod, TVS, pojistek a dalších prvků.
- Zkontrolovat footprinty.
- Doplnit chybějící pasivy kolem buck měniče.
- Doplnit nebo ověřit vstupní ochrany.
- Doplnit nebo ověřit RS-485 terminaci, bias rezistory a jumpery.
- Doplnit blokovací kondenzátory u všech IC.
- Zkontrolovat napájecí větve a jejich názvy.
- Zkontrolovat GND návrh.
- Doplnit testpointy.
- Spustit ERC a chyby řešit nebo zdokumentovat.

2. TWN4 carrier
- Neřeš mechanickou konstrukci jako finální návrh.
- Přesto zkontroluj elektrické připojení TWN4.
- Ověř konektor X2 / COM1 / TTL / napájení / GND.
- Eviduj nutné mechanické údaje jako TODO:
  - přesná poloha pinů,
  - výška konektoru,
  - protikus Samtec 2×12 2.00 mm,
  - montážní otvory,
  - výška standoffů.
- Pokud nejsou mechanická data jistá, navrhni prototyp tak, aby šel servisně ověřit, ale jasně označ riziko.

3. Napájení
- Navrhni/ověř vstup 12–48 V.
- Ověř ochranu proti přepólování.
- Ověř pojistku/polyfuse.
- Ověř TVS na vstupu.
- Ověř buck měnič na 5 V.
- Spočítej přibližnou proudovou rezervu.
- Doporuč konkrétní hodnoty pasivů podle datasheetu měniče.
- Zkontroluj rozmístění vstupních/výstupních kondenzátorů.
- Přidej testpointy:
  - VIN,
  - +5V,
  - případně +3V3,
  - GND.

4. RS-485 / OSDP
- Na začátek počítej s OSDP přes RS-485.
- BLE neřeš v této první výrobní větvi; pouze ho uveď jako budoucí možnost.
- Ověř RS-485 transceiver.
- Ověř polaritu A/B.
- Ověř řízení DE/RE.
- Ověř možnost terminace 120 Ω jumperem/DIPem.
- Ověř bias rezistory jumperem/DIPem.
- Doporuč, jestli má být galvanické oddělení už v Rev B, nebo až Rev C.
- Pokud galvanické oddělení není nutné pro první prototyp, zdokumentuj proč.
- Přidej testpointy:
  - RS485_A,
  - RS485_B,
  - TX,
  - RX,
  - DE/RE,
  - GND.

5. Zámek / relé / výstupy
- Ověř proudové nároky zámku.
- Ověř ochranu proti indukční špičce.
- Doplnit flyback diodu / TVS / snubber podle typu výstupu.
- Přidej možnost odpojit lock část jumperem nebo servisním propojovacím bodem.
- Ověř dimenzování tranzistoru/MOSFETu/relé.
- Ověř šířky cest pro proud zámku.
- Zajisti jasně pojmenované svorky.
- Přidej měřicí body.

6. Vstupy
- Ověř vstupní ochrany na dlouhé kabely.
- Doplnit pull-up/pull-down podle logiky.
- Doplnit RC filtraci, pokud dává smysl.
- Ověř ESD/TVS ochranu.
- Jasně označ logiku vstupů.

7. PCB Rev B
- Po vyčištění schématu vytvoř nebo uprav PCB.
- První prototyp dělej servisní, ne miniaturní.
- Použij větší testpointy.
- Dej rozumné clearance mezi napájecími částmi.
- Odděl výkonovou část zámku od logiky.
- Drž buck layout podle datasheetu.
- Umísti ochrany co nejblíže konektorům.
- Umísti terminaci a bias RS-485 blízko transceiveru nebo konektoru podle smyslu návrhu.
- Zkontroluj návratové proudy.
- Přidej popisky na silkscreen:
  - VIN polarity,
  - RS485 A/B,
  - LOCK,
  - RELAY,
  - INPUTS,
  - 5V,
  - GND,
  - JUMPER terminace,
  - JUMPER bias,
  - REV označení.
- Spusť DRC a oprav chyby.

8. JLCPCB výstupy
Připrav výrobní výstupy:
- Gerber files,
- Drill files,
- BOM,
- Pick & Place / CPL,
- poznámky k osazení,
- seznam dílů vhodných pro JLCPCB/LCSC, pokud je možné,
- seznam dílů, které bude nutné osadit ručně,
- README pro výrobu,
- manufacturing checklist.

Výstupy ulož do struktury například:

/reports
  001_initial_state.md
  002_schematic_cleanup.md
  003_power_review.md
  004_rs485_review.md
  005_lock_relay_io_review.md
  006_pcb_layout_review.md
  007_jlcpcb_export_review.md
  008_final_prototype_readiness.md

/manufacturing
  /rev_b
    gerbers/
    drill/
    bom/
    pick_place/
    README_JLCPCB.md
    assembly_notes.md
    known_risks.md
    prototype_test_plan.md

/docs
  architecture.md
  electrical_assumptions.md
  revision_history.md
  testpoints.md
  bringup_plan.md

9. Reporty
Po každé větší části vytvoř report v Markdownu.
Každý report musí obsahovat:
- co bylo změněno,
- proč to bylo změněno,
- jaké předpoklady byly použity,
- co bylo ověřeno,
- co zůstává rizikem,
- co je další krok,
- odkazy na relevantní soubory,
- výsledek ERC/DRC, pokud se týká dané fáze.

10. Git commity a verze
Pracuj průběžně přes git.
Po každém logickém kroku udělej commit.
Commity piš jasně, například:
- rev-b: create production prototype branch
- rev-b: clean schematic symbols and footprints
- rev-b: add power input protection and buck passives
- rev-b: add rs485 termination bias and testpoints
- rev-b: add lock output protection and service jumpers
- rev-b: route initial pcb layout
- rev-b: fix drc and silkscreen labels
- rev-b: export jlcpcb manufacturing package
- docs: add prototype bring-up test plan

Zaveď nebo aktualizuj verzování projektu:
- Rev B jako pracovní výrobní prototyp.
- Přidej revision_history.md.
- Přidej jasné označení aktuální verze.
- Nepřepisuj staré výrobní výstupy bez archivace.

11. Kontrolní seznam před výrobou
Před finálním exportem vytvoř checklist:
- ERC bez kritických chyb.
- DRC bez kritických chyb.
- Všechny součástky mají hodnotu.
- Všechny součástky mají footprint.
- Kritické součástky mají ověřený datasheet.
- Napájecí větve jsou pojmenované a měřitelné.
- Testpointy jsou dostupné.
- RS-485 A/B je jasně označené.
- Terminace a bias jsou volitelné.
- Lock část lze servisně odpojit.
- Vstupní ochrany jsou osazené.
- BOM odpovídá PCB.
- Pick&Place odpovídá footprintům.
- Gerbery byly otevřeny a zkontrolovány v Gerber vieweru.
- Silkscreen nezasahuje do padů.
- Polarita konektorů, diod, elektrolytů a IC je jasná.
- Jsou zdokumentovaná rizika.
- Je připraven bring-up plán.

12. Bring-up plán prototypu
Vytvoř plán prvního oživení:
- vizuální kontrola PCB,
- kontrola zkratů mezi VIN/GND/5V/3V3,
- první napájení přes laboratorní zdroj s proudovým limitem,
- měření 5 V větve bez TWN4,
- měření 5 V větve s TWN4,
- kontrola RS-485 TX/RX/DE/RE,
- test OSDP komunikace,
- test vstupů,
- test relé,
- test zámku nejprve bez reálné zátěže,
- test zámku s reálnou zátěží přes proudový limit,
- záznam výsledků do reportu.

13. Co teď neřešit
- Neřeš finální mechanickou konstrukci.
- Neřeš BLE jako součást první výrobní desky.
- Neřeš design krabičky.
- Neřeš finální estetiku.
- Neřeš masovou výrobu, dokud není ověřen první servisní prototyp.

14. Výstup, který od tebe očekávám
Na konci práce chci mít:
- čisté KiCad schéma Rev B,
- PCB Rev B,
- reporty,
- git commity,
- revision history,
- výrobní složku pro JLCPCB,
- BOM,
- Pick&Place,
- Gerbery,
- Drill files,
- assembly notes,
- known risks,
- bring-up/test plán,
- jasné doporučení, jestli je prototyp připraven k objednání, nebo co přesně ještě blokuje výrobu.

Pracuj postupně, pečlivě a samostatně. Každé rozhodnutí zapisuj. Pokud něco nevíš, udělej nejlepší inženýrský předpoklad, označ ho jako ASSUMPTION a pokračuj. Cílem je dostat projekt z aktuální Rev B fáze do reálně objednatelného a měřitelného prototypu.

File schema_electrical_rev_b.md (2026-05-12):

# TWN4 Access System - elektricke schema Rev B

Tento dokument prevadi puvodni blokovy navrh na konkretnejsi elektricke schema pro prvni prototyp. Stale nejde o finalni vyrobni dokumentaci, ale uz jsou zde konkretni soucastky, hodnoty, nety a rozhrani.

Schema je rozdeleno na dve desky:

1. `reader-carrier`: deska u dveri s TWN4, RS-485, napajenim, rele, vystupem pro zamek a vstupy.
2. `rpi-gateway`: deska/HAT u Raspberry Pi, ktera dela centralni RS-485 rozhrani a pripadne distribuci napajeni po kabelu.

## 1. Reader carrier

### 1.1 Konektory

#### J1 - vstup napajeni

```text
J1.1  VIN_IN   12-48 V DC
J1.2  GND_IN
```

Doporuceni:

- svorkovnice 2pin, roztec 5.08 mm
- vstup navrhovat tak, aby prezil bezne 48V instalace a PoE-like pasivni napajeni
- pro skutecne 802.3af/at PoE je pozdeji potreba PoE PD front-end

#### J2 - RS-485 sbernice

```text
J2.1  RS485_A
J2.2  RS485_B
J2.3  GND_BUS
J2.4  SHIELD
```

`SHIELD` vest na samostatny pad / svorku. Pro Rev B:

```text
SHIELD -> JP_SHIELD -> chassis/mechanical GND
SHIELD -> C_SHIELD 4.7 nF / 100 V -> GND
SHIELD -> R_SHIELD 1 M -> GND
```

#### J3 - rele kontakt

```text
J3.1  RELAY_COM
J3.2  RELAY_NO
J3.3  RELAY_NC
```

Pouziti: bezpotencialovy impuls do dverni jednotky.

#### J4 - primy vystup pro zamek

```text
J4.1  LOCK+
J4.2  LOCK-
```

Rev B varianta:

```text
LOCK+ = VIN_LOCK
LOCK- = spinane pres N-MOSFET na GND_POWER
```

`VIN_LOCK` je volitelne:

```text
JP_LOCK_SUPPLY:
1-2 = VIN_LOCK z VIN_PROT
2-3 = VIN_LOCK z externi svorky J7
```

#### J5 - vstupy

```text
J5.1  DOOR_CONTACT
J5.2  REX_BUTTON
J5.3  TAMPER
J5.4  GND_IO
```

Vstupy jsou navrzene jako suche kontakty proti zemi.

#### J6 - TWN4 X2 socket

Konektor:

- 2x12
- roztec 2.00 mm
- protikus pro TWN4 X2
- kandidat: Samtec `PTF-124-01-S-D` nebo kompatibilni 2x12 female socket

Pouzite piny:

```text
X2.3   I2C_SCL
X2.4   I2C_SDA
X2.10  HOSTSENSE
X2.12  GND
X2.13  +5V_TWN4
X2.17  COM1_TX
X2.18  COM1_RX
X2.19  VCC_3V3_REF
X2.20  GPIO4_RS485_DIR
X2.21  GPIO5_RELAY
X2.22  GPIO6_LOCK
X2.23  PWRDWN_N
X2.24  RESET_N
```

`HOSTSENSE`:

```text
JP_HOSTSENSE:
1-2 osazeno: HOSTSENSE -> GND, ctecka bezi pres COM1
open: internal pull-up, USB rezim
```

Pro dverni modul bude osazeno `HOSTSENSE -> GND`.

### 1.2 Vstupni ochrana a napajeni

#### F1 - vstupni pojistka

```text
VIN_IN -> F1 -> VIN_FUSED
```

Doporuceni:

- pro logiku a maly zamek: vratna polyfuse 1.1-1.5 A hold, napeti aspon 60 V
- pro instalacni verzi radeji tavna pojistka nebo eFuse podle proudoveho rozpoctu

#### U1 - vstupni ochrana, Rev B kandidat

Pro robustni vstup je vhodny `LTC4367`:

- 2.5-60 V operating range
- ochrana proti prepeti az 100 V
- ochrana proti podpeti a reverse supply
- ridi back-to-back N-MOSFETy

Rev B doporuceni:

```text
VIN_FUSED -> LTC4367 + back-to-back MOSFETs -> VIN_PROT
```

Nastaveni prahu:

```text
UVLO: priblizne 10.5 V
OVLO: priblizne 60 V
```

Poznamka: Delice UV/OV je nutne prepocitat presne podle finalni zvolene varianty `LTC4367` a datasheetove rovnice. Pro prvni KiCad kresbu je tato cast oznacena jako `front-end protection`.

Jednodussi alternativa pro laboratorni prototyp:

```text
VIN_IN -> F1 -> Schottky/rectifier diode 100 V -> VIN_PROT
VIN_PROT -> TVS -> GND
```

Tato varianta je jednodussi, ale hreje a neni tak elegantni pri vyssich proudech.

#### D1 - vstupni TVS

Kandidat:

```text
D1 = SMBJ58A nebo ekvivalent pro 48V system
```

Poznamka:

- vhodne pro pasivni 48V napajeni, kde normalni maximum muze byt blizko 57 V
- finalni TVS zvolit az podle zvolene vstupni ochrany, aby clamp neprekracoval limity dalsich obvodu

#### U2 - buck 5 V

Kandidat:

```text
U2 = TI LM5164
```

Vlastnosti:

- vstup 6-100 V
- vystup az 1 A
- vhodne pro 12-48 V vstup s rezervou

Navrh podle TI 5V aplikace:

```text
U2 VIN   -> VIN_PROT
U2 VOUT  -> +5V
U2 GND   -> GND
```

Hodnoty:

```text
CIN1, CIN2   2.2 uF / 100 V / X7R
CIN_BULK     47 uF / 100 V electrolytic nebo polymer
L1           68 uH, Isat > 1.8 A, nizky DCR
COUT1,COUT2  22 uF / 25 V / X7R
RFB_TOP      453 k / 1 %
RFB_BOT      49.9 k / 1 %
RRON         100 k / 1 %
RA           453 k / 1 %
CA           3.3 nF
CB           56 pF
CBST         2.2 nF
```

Poznamka: Tyto hodnoty vychazi z TI prikladoveho 5V navrhu. Layout bucku musi byt kreslen podle datasheetu, jinak bude zdroj zbytecne rusit RFID/BLE cast.

#### U3 - 3.3 V regulator

Kandidat:

```text
U3 = TLV75533PDBVR nebo ekvivalent 3.3 V LDO
```

Zapojeni:

```text
+5V -> U3 IN
U3 OUT -> +3V3
U3 GND -> GND
```

Hodnoty:

```text
CIN  1 uF / 10 V
COUT 1 uF / 10 V
```

`+3V3` napaji:

- RS-485 transceiver
- MCP23008
- I2C pull-upy
- drobnou logiku

### 1.3 TWN4 napajeni

```text
+5V -> J6 X2.13 +5V_TWN4
GND -> J6 X2.12
```

Pridat:

```text
C_TWN4_LOCAL 10 uF / 10 V u J6
C_TWN4_HF    100 nF u J6
FB_TWN4      optional ferrite bead mezi +5V a +5V_TWN4
```

`VCC_3V3_REF` z X2.19 nebrat jako zdroj pro carrier. Jen testpoint / reference.

### 1.4 RS-485 reader side

#### U4 - RS-485 transceiver

Kandidat:

```text
U4 = TI THVD1450
```

Vlastnosti:

- 3.0-5.5 V supply
- half-duplex RS-485
- vhodny pro 3.3V logiku
- integrovana ESD odolnost

Zapojeni:

```text
J6 X2.17 COM1_TX -> R_TX 33 R -> U4 DI
J6 X2.18 COM1_RX <- R_RX 33 R <- U4 RO
J6 X2.20 GPIO4   -> R_DIR 100 R -> U4 DE
J6 X2.20 GPIO4   -> R_DIR 100 R -> U4 /RE
U4 VCC -> +3V3
U4 GND -> GND
```

Toto zapojeni pouziva:

```text
GPIO4 low  = prijem: driver off, receiver on
GPIO4 high = vysilani: driver on, receiver off
```

Default:

```text
R_DIR_PD = 100 k z GPIO4_RS485_DIR na GND
```

Tedy po resetu je transceiver v prijmu.

Poznamka: Pokud bude potreba poslouchat vlastni vysilani, musi se `DE` a `/RE` ridit oddelene nebo pres invertor.

#### RS-485 ochrana a terminace

```text
U4 A -> R_A_SER 10 R -> RS485_A
U4 B -> R_B_SER 10 R -> RS485_B
D2 = SM712 mezi RS485_A / RS485_B / GND
```

Terminace:

```text
RS485_A -> JP_TERM -> R_TERM 120 R -> RS485_B
```

Bias, osazovat jen pokud je modul na konci / jako master podle sbernice:

```text
R_BIAS_UP   680 R: RS485_A -> +3V3, pres jumper
R_BIAS_DOWN 680 R: RS485_B -> GND, pres jumper
```

Poznamka: Znaceni A/B se mezi vyrobci umi prohodit. Pred PCB finalizaci overit polaritu s realnym THVD1450 a RPi stranou.

### 1.5 Rele vystup

#### K1 - rele

Kandidat:

```text
K1 = Omron G5V-2 DC5 nebo ekvivalent DPDT 5V signal relay
```

Pouzije se jeden prepinaci kontakt:

```text
K1 COM -> J3.1 RELAY_COM
K1 NO  -> J3.2 RELAY_NO
K1 NC  -> J3.3 RELAY_NC
```

Driver:

```text
J6 X2.21 GPIO5_RELAY -> R_G2 100 R -> Q2 gate
Q2 = 2N7002
Q2 source -> GND
Q2 drain -> K1 coil low
K1 coil high -> +5V
D3 flyback diode paralelne k civce, katoda na +5V
R_PD2 100 k gate -> GND
```

D3:

```text
D3 = 1N4148 / BAV99 / SS14 podle civkoveho proudu
```

### 1.6 Primy lock vystup

Rev B pouziva low-side MOSFET.

```text
VIN_LOCK -> J4.1 LOCK+
J4.2 LOCK- -> Q3 drain
Q3 source -> GND_POWER
```

Kandidat MOSFET:

```text
Q3 = 100V N-MOSFET s Rds(on) specifikovanou pri Vgs = 4.5 V
priklad: Diodes Inc. DMT10H015LSS nebo podobny
```

Gate driver:

```text
J6 X2.22 GPIO6_LOCK -> U6 input
U6 = SN74AHCT1G125 nebo podobny 5V TTL-compatible buffer
U6 VCC -> +5V
U6 output -> R_G3 47 R -> Q3 gate
R_PD3 100 k -> Q3 gate to GND
```

Duvod: TWN4 GPIO je 3.3V logika. Pro 100V MOSFET je lepsi mit gate drive 5 V, pokud je Rds(on) garantovana pri 4.5 V.

Ochrana zamku:

```text
D4 flyback diode pres zamek, pokud je zamek DC civka
D5 TVS na LOCK+ / LOCK- podle napeti zamku
F_LOCK pojistka v ceste VIN_LOCK
```

Doporuceni:

```text
F_LOCK = podle ciloveho zamku, napr. 1 A nebo 2 A
D5 = TVS podle 12/24/48V lock varianty
```

Pozor: Pokud je vstup 48 V, `LOCK+` bude 48 V, pokud neni pouzit externi 12V zdroj nebo samostatny 12V menic.

### 1.7 Vstupy DOOR / REX / TAMPER

#### U5 - I2C IO expander

Kandidat:

```text
U5 = MCP23008
```

Zapojeni:

```text
J6 X2.3 I2C_SCL -> R_SCL_SER 33 R -> U5 SCL
J6 X2.4 I2C_SDA -> R_SDA_SER 33 R -> U5 SDA
R_SCL_PULL 4.7 k -> +3V3
R_SDA_PULL 4.7 k -> +3V3
U5 VDD -> +3V3
U5 VSS -> GND
U5 RESET -> R_RESET 10 k -> +3V3
U5 A0,A1,A2 -> GND
```

Adresa:

```text
MCP23008 address = 0x20
```

Vstup jednoho kontaktu:

```text
J5 input -> R_IN_SER 1 k -> U5 GPx
U5 GPx -> R_IN_PULL 10 k -> +3V3
U5 GPx -> C_IN 100 nF -> GND
J5 input -> ESD diode -> GND/+3V3 nebo maly TVS na GND
```

Mapovani:

```text
GP0 = DOOR_CONTACT
GP1 = REX_BUTTON
GP2 = TAMPER
GP3 = AUX_IN
GP4-GP7 = rezerva / LED / DIP adresa
```

Pro kabelove vstupy v realne instalaci zvazit optocleny nebo robustnejsi vstupni ochranu.

### 1.8 Diagnostika

LED:

```text
LED_PWR: +5V pres 2.2 k -> LED -> GND
LED_RS485_TX: GPIO4 nebo U4 DE pres 2.2 k -> LED -> GND
LED_RELAY: GPIO5 pres 2.2 k -> LED -> GND
LED_LOCK: U6 output pres 2.2 k -> LED -> GND
```

Testpointy:

```text
TP_VIN_PROT
TP_5V
TP_3V3
TP_GND
TP_COM1_TX
TP_COM1_RX
TP_RS485_A
TP_RS485_B
TP_GPIO4_DIR
TP_GPIO5_RELAY
TP_GPIO6_LOCK
```

## 2. RPi gateway / HAT

RPi strana ma byt jednodussi nez reader carrier. Jejich ukol je:

- prevod UART RPi na RS-485
- terminace/bias na strane masteru
- volitelna distribuce `VIN_BUS` do kabelu

### 2.1 Konektory

#### J10 - Raspberry Pi 40pin header subset

Pouzite piny:

```text
Pin 1   +3V3
Pin 2   +5V
Pin 6   GND
Pin 8   GPIO14 / TXD
Pin 10  GPIO15 / RXD
Pin 12  GPIO18 / RS485_DIR
Pin 14  GND
```

#### J11 - RS-485 bus

```text
J11.1 RS485_A
J11.2 RS485_B
J11.3 GND_BUS
J11.4 VIN_BUS optional
```

#### J12 - napajeni sbernice

```text
J12.1 VIN_BUS_IN 12-48 V
J12.2 GND_BUS
```

### 2.2 RS-485 transceiver

Kandidat:

```text
U10 = TI THVD1450
```

Zapojeni:

```text
RPi GPIO14 TXD -> R10 33 R -> U10 DI
RPi GPIO15 RXD <- R11 33 R <- U10 RO
RPi GPIO18 DIR -> R12 100 R -> U10 DE
RPi GPIO18 DIR -> R12 100 R -> U10 /RE
R13 100 k: DIR -> GND
U10 VCC -> +3V3_RPI
U10 GND -> GND
```

Bus:

```text
U10 A -> R14 10 R -> RS485_A
U10 B -> R15 10 R -> RS485_B
D10 = SM712 na A/B
JP10 + R16 120 R terminace
JP11 + R17 680 R pull-up bias
JP12 + R18 680 R pull-down bias
```

Na master strane bude typicky osazena bias sada. Terminace pouze pokud je RPi na konci sbernice.

### 2.3 VIN_BUS distribuce

Pokud RPi gateway napaji sbernici:

```text
J12 VIN_BUS_IN -> F10 -> VIN_BUS -> J11.4
J12 GND_BUS -> J11.3
D11 TVS na VIN_BUS
LED_BUS_POWER pres 10 k
```

Hodnoty:

```text
F10 podle celkoveho proudu sbernice
D11 SMBJ58A nebo podle realneho VIN_BUS
```

Poznamka: Nepouzet 5V z Raspberry Pi pro napajeni ctecek na dlouhem kabelu. Sbernice ma mit vlastni 12/24/48V zdroj.

## 3. Net naming

Hlavni nety:

```text
VIN_IN
VIN_FUSED
VIN_PROT
VIN_LOCK
+5V
+3V3
GND
GND_POWER
GND_BUS
RS485_A
RS485_B
COM1_TX
COM1_RX
GPIO4_RS485_DIR
GPIO5_RELAY
GPIO6_LOCK
I2C_SCL
I2C_SDA
DOOR_CONTACT
REX_BUTTON
TAMPER
```

## 4. Kriticke body k overeni

1. `COM1_TX` / `COM1_RX` jsou v dokumentaci popsane jako low active TTL. Pred definitivnim zapojenim overit osciloskopem, zda neni potreba inverze.
2. A/B polarita RS-485 se musi overit proti realnemu transceiveru a OSDP stacku.
3. `GPIO4` rizeni DE/RE musi byt synchronizovane s vysilanim OSDP ramcu.
4. Buck `LM5164` musi mit layout podle datasheetu, jinak muze rusit RFID/BLE.
5. BLE antenni cast TWN4 nesmi byt prekryta medi ani kovem.
6. Lock vystup se musi dimenzovat podle realneho typu zamku.
7. Pokud bude skutecne 802.3af/at PoE, musi prijit samostatna PoE PD varianta.

## 5. Minimalni Rev B BOM

Viz `bom_rev_b.csv`.

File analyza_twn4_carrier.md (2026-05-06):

# TWN4 MultiTech 3 BLE - carrier deska pro RS-485 / OSDP

## Cil

Cilem je nahradit soucasne provizorni zapojeni:

- na strane ctecky: TTL -> RS-485 modul
- na strane Raspberry Pi: RS-485 -> TTL -> USB prevodnik CP2102

novou cistou carrier deskou pro ctecku ELATEC TWN4 MultiTech 3 BLE. Deska ma ctecku mechanicky prijmout bez pajeni dratku primo na piny, napajet ji, pripojit ji na RS-485 sbernici a do budoucna umoznit i ovladani dverniho zamku, vstupy a BLE identifikaci.

## Shrnuti doporucene architektury

```text
VIN 12-48 V DC, navrhove radeji 12-60 V tolerantni
   |
   +-- ochrana vstupu
   +-- buck menic na 5 V pro TWN4
   +-- RS-485 transceiver pro COM1
   +-- rele COM/NO/NC
   +-- spinany LOCK vystup
   +-- vstupy: dverni kontakt, REX, tamper
   |
TWN4 MultiTech 3 BLE
   |
   +-- RFID / NFC / BLE credential
   +-- komunikace pres RS-485 / OSDP do RPi nebo kontroleru
```

Preferovana komunikace do systemu je RS-485 s adresnym protokolem, idealne OSDP. Wiegand a Omron davaji smysl hlavne jako vystupni formaty pro kompatibilitu se starsimi pristupovymi systemy, ne jako hlavni komunikace pro Raspberry Pi.

## Mechanicke reseni

Nejcistsi reseni je carrier / baseboard deska, do ktere se TWN4 zasune jako modul.

Podle dokumentace ma TWN4 MultiTech 3 BLE genericky konektor X2:

- 2x12 pin header
- roztec 2.00 mm
- v dokumentaci je jako priklad uveden Samtec `PTT-124-01-S-D`

Na carrier desce by mel byt odpovidajici 2x12 female socket / receptacle s rozteci 2.00 mm. Ctecka se zasune do konektoru a mechanicky se zajisti pres distancni sloupky nebo pritlacny ramecek.

Varianty:

- female socket + distancni sloupky: nejvhodnejsi pro trvale zarizeni
- pogo piny + pritlak pres sroubky: vhodne spis pro testovaci fixture nebo pokud nejsou osazene piny

Sroubky nemaji delat elektricky kontakt. Maji pouze drzet geometrii, aby konektor nebyl namahany vibracemi nebo kroucenim.

## Relevantni piny TWN4

Z konektoru X2 jsou pro prvni prototyp dulezite hlavne:

```text
X2 pin 12  GND
X2 pin 13  UVCC, USB VCC 5 V
X2 pin 17  COM1_TX, low active TTL output
X2 pin 18  COM1_RX, low active TTL input, internal pull-up
X2 pin 19  VCC 3.3 V za regulatorem
X2 pin 20  GPIO4
X2 pin 21  GPIO5
X2 pin 22  GPIO6
```

Poznamky:

- `VCC 3.3 V` z TWN4 nepouzivat jako zdroj pro vetsi externi zatez. Maximalne jako logickou referenci.
- COM1 je vhodny pro host komunikaci / RS-485 prevod.
- U BLE varianty je COM2 rezervovany pro BLE modul a GPIO7 je reset BLE modulu. Nepouzivat je pro vlastni funkce.
- GPIO0 az GPIO2 jsou v API spojene s LED funkcemi, proto je lepsi pro vlastni veci preferovat GPIO4 az GPIO6.

## GPIO moznosti

TWN4 API umoznuje GPIO pouzit jako:

- vstup s internim pull-up, pull-down nebo bez pullu
- vystup push-pull nebo open-drain
- cteni logicke urovne
- nastaveni / shozeni / prepinani vystupu
- blikani nebo jednoduchy obdelnikovy prubeh
- interrupt na nabeznou, sestupnou nebo obe hrany
- Wiegand vystup
- Omron clock/data vystup

Prakticke pouziti na carrier desce:

- GPIO pro rizeni `DE/RE` RS-485 transceiveru
- vystup pro rele nebo MOSFET lock driver
- vstup pro tamper
- vstup pro dverni kontakt
- vstup pro odchodove tlacitko REX
- lokalni signalizace

## RS-485 a OSDP

RS-485 je vhodna volba pro zlevneni kabelaze. Misto jednoho kabelu pro kazdou ctecku lze vest jednu sbernici:

```text
kontroler / RPi
   |
   |  +24/48 V, GND, RS485 A, RS485 B
   |
ctecka 1, adresa 1
ctecka 2, adresa 2
ctecka 3, adresa 3
```

Nutne zasady:

- vest jako sbernici, ne jako hvezdu
- terminace 120 R jen na obou koncich sbernice
- bias odpory pouze jednou, typicky u masteru, nebo konfigurovatelne jumperem
- pouzit krouceny par pro A/B
- pri dlouhych trasach zvazit izolovanou RS-485
- napajeni 24 V nebo 48 V je vyhodnejsi nez 12 V kvuli ubytkum na kabelu

OSDP je vhodnejsi nez Wiegand, protoze:

- bezi nad RS-485
- podporuje adresovani vice ctecek
- umi obousmernou komunikaci
- umi LED, bzucek, vstupy a vystupy
- umi zabezpeceny kanal ve vyssich rezimech
- je to standard pro pristupove systemy

Wiegand je proti tomu jednoduche jednosmerne posilani bitu bez potvrzeni, adresovani a zabezpeceni.

## RS-485 hardware

Doporucene vybaveni RS-485 casti:

- moderni RS-485 transceiver vhodny pro logiku TWN4
- TVS ochrana na linkach A/B
- jumper pro 120 R terminaci
- jumper pro bias odpory
- konektor A/B/GND
- pripadne izolovana varianta pro delsi trasy nebo rusne prostredi

Smer vysilani:

- bud ridit `DE/RE` pomoci GPIO, napr. GPIO4
- nebo pouzit transceiver s automatickym rizenim smeru

Pro prvni prototyp je jednodussi auto-direction transceiver. Pro robustni OSDP implementaci muze byt lepsi mit `DE/RE` pod plnou kontrolou firmware.

## Napajeni 12-48 V

Vstup 12-48 V DC je vhodny, ale soucastky je lepsi dimenzovat s rezervou na 60 V. Duvodem jsou spicky a realne chovani 48V systemu.

Doporucena vstupni cast:

- pojistka nebo eFuse
- ochrana proti prepolovani
- TVS dioda vhodna pro 48V systemy
- vstupni filtr
- buck menic na 5 V pro TWN4

TWN4 napajet z 5 V vetve. Zamek a silove vystupy drzet oddelene od logiky, hlavne z hlediska zemnich cest a proudovych spicek.

## PoE poznamka

Pokud jde o pasivni PoE, tedy 48 V DC primo na vodicich, lze ho brat jako bezny 48V vstup, pokud je deska na to navrzena.

Pokud jde o skutecne IEEE 802.3af/at PoE, nestaci jen pripojit 48 V. Deska potrebuje PoE PD controller nebo hotovy PoE modul, ktery se vuci switchi spravne identifikuje a vyjedna napajeni.

Doporuceni:

- prvni varianta desky: DC vstup 12-48 V, navrhove 60 V tolerantni
- pozdejsi varianta: PoE 802.3af/at s PD modulem

## Vystup pro zamek

Deska by mela umet dve veci:

1. Bezpotencialovy vystup do dverni jednotky:

```text
RELAY COM
RELAY NO
RELAY NC
```

2. Primy vystup pro zamek:

```text
LOCK+ = VIN nebo externi napajeni zamku
LOCK- = spinane pres MOSFET
```

Poznamky:

- rele COM/NO/NC je nejuniverzalnejsi pro napojeni do existujici jednotky
- MOSFET vystup je vhodny pro prime kratke pusteni napeti do zamku
- zamek muze byt 12 V, 24 V nebo 48 V podle napajeni a typu
- pokud je VIN 48 V, musi byt zamek take urceny pro 48 V, pokud deska nema samostatny menic na 12 V

Ochrany pro zamek:

- samostatna pojistka nebo proudove omezeni
- flyback dioda nebo TVS proti indukcni spicce
- MOSFET s dostatecnou rezervou napeti a proudu
- oddelene silove cesty na PCB

Fail-safe / fail-secure:

- fail-secure: bez napeti zamceno, impulsem se otevira
- fail-safe: pod napetim drzi, pri vypadku napajeni otevira

Deska by mela podporovat oba scenare alespon pres rele NO/NC. Primy lock vystup musi byt navrzen s ohledem na konkretni typ zamku.

## Vstupy

Doporucene vstupy na carrier desce:

- tamper
- dverni kontakt
- REX / odchodove tlacitko

Vstupy by mely mit:

- ochranu proti ESD a prepeti
- filtrovani zakmitu
- moznost pull-up / pull-down
- idealne svorky pro bezne instalacni kontakty

## BLE budoucnost

TWN4 MultiTech 3 BLE ma BLE modul. Dokumentace zminuje podporu BLE credentialu a API funkce jako:

- `BLEInit`
- `BLEDiscover`
- `BLEConnectToDevice`
- GATT read/write
- RSSI request
- transparentni BLE prenos

Podporovane nebo zminene credential scenare:

- Mobile Badge BLE NFC
- KleverKey
- Safetrust
- HID Mobile Access
- PKOC
- custom GATT / transparentni prenos

Doporucena architektura do budoucna:

```text
telefon / BLE credential
        |
        v
TWN4 MultiTech 3 BLE
        |
        v
OSDP pres RS-485
        |
        v
RPi / kontroler
```

Tedy BLE by nemelo byt oddelene paralelni reseni. TWN4 by nacetla BLE credential stejne jako kartu a pres OSDP/RS-485 by predala udalost kontroleru.

Pozor:

- RSSI neni bezpecnostni overeni, pouze orientacni signal o vzdalenosti
- pro otevreni dveri nepouzivat jen MAC adresu nebo beacon
- pro realne nasazeni je vhodny kryptograficky credential
- BLE antena nesmi byt zakryta medi, kovem nebo spatne navrzenou carrier deskou
- u sendvicove mechaniky nechat keepout v oblasti anteny
- iOS/Android maji omezeni behu aplikaci na pozadi

## Omron a Wiegand

Omron:

- dvoulinkovy clock/data vystup
- jedna linka je hodinovy signal, druha data
- vhodne jen pro zarizeni, ktera tento format ocekavaji
- neni to robustni adresna sbernice

Wiegand:

- dve linky DATA0 a DATA1
- bit 0 je impuls na DATA0
- bit 1 je impuls na DATA1
- velmi rozsirene ve starsich pristupovych systemech
- jednoduche, ale jednosmerne a bez zabezpeceni

Vyhody Wiegandu:

- jednoducha integrace se starsimi jednotkami
- rozsireny standard v pristupovych systemech
- snadna diagnostika logickym analyzatorem

Nevyhody Wiegandu:

- jednosmerny prenos
- bez potvrzeni doruceni
- bez adresovani
- bez sifrovani
- nevhodne pro bohatou komunikaci s RPi

Pro tento projekt je hlavni cesta RS-485 / OSDP. Wiegand a Omron jsou jen kompatibilni vystupni rezimy.

## Navrh prvniho prototypu

Prvni prototyp by mel byt radeji jednoduchy a overit zakladni predpoklady.

Minimalni prototyp:

- carrier deska pro TWN4 X2
- vstup 12-48 V DC, soucastky dimenzovat na 60 V
- buck 5 V pro TWN4
- RS-485 transceiver na COM1
- jumper terminace 120 R
- jumper bias
- svorkovnice A/B/GND/VIN
- testpointy pro COM1_TX, COM1_RX, GPIO4, 5 V, GND
- mechanicke uchyceni ctecky

Druha iterace:

- rele COM/NO/NC
- MOSFET LOCK vystup
- vstupy tamper / door / REX
- LED diagnostika
- OSDP firmware

Treti iterace:

- izolovana RS-485 varianta
- PoE 802.3af/at varianta
- BLE credential integrace

## Otevrene otazky

- Je na konkretni TWN4 fyzicky osazeny X2 header, nebo pouze pady?
- Jake jsou presne rozmery a vyska konektoru v konkretni mechanice?
- Bude hlavni kabel nest i napajeni zamku, nebo bude zamek napajen lokalne?
- Jaky proud a typ zamku se ma podporovat?
- Kolik ctecek bude typicky na jedne sbernici?
- Ma byt OSDP implementovano primo ve firmware TWN4, nebo ma carrier obsahovat dalsi MCU?
- Je cil podporovat pouze pasivni 48V PoE, nebo i skutecne IEEE 802.3af/at?

## Doporuceny smer

Nejlepsi smer je postavit z toho modul:

- TWN4 jako RFID/NFC/BLE jadro
- carrier deska jako napajeci, komunikacni a dverni elektronika
- RS-485 / OSDP jako hlavni komunikace
- 12-48 V DC vstup s rezervou na 60 V
- rele a MOSFET vystup pro flexibilni ovladani dveri
- vstupy pro dverni logiku
- BLE credential jako budouci rozsireni pres samotnou ctecku

Takovy modul by mohl vyrazne snizit cenu kabelaze a zjednodusit montaz, protoze vice ctecek muze byt na jedne adresne RS-485 sbernici.

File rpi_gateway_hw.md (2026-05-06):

# Raspberry Pi strana - RS-485 gateway / HAT

## Proc resit HW i na strane RPi

Ano, i na strane Raspberry Pi dava smysl udelat vlastni hardware. Soucasny retezec:

```text
RS-485 -> TTL RS-485 modul -> CP2102 USB-UART -> RPi USB
```

funguje, ale je to zbytecne poskladane z vice modulu. Pro cisty system jsou lepsi dve varianty.

## Varianta A - RPi HAT pres UART

Nejcistsi varianta pro centralni jednotku s Raspberry Pi:

```text
RPi GPIO UART
   |
   v
RS-485 transceiver
   |
   v
RS-485 A/B sbernice ke cteckam
```

Pouzite signaly RPi:

```text
GPIO14 / TXD  -> RS-485 DI
GPIO15 / RXD  <- RS-485 RO
GPIO18        -> DE/RE smer RS-485
GND           -> reference
3V3           -> logika transceiveru
```

Vyhody:

- zadny USB prevodnik navic
- mensi cena
- mensi mechanicky chaos
- primo riditelne z Linuxu
- dobre pro instalaci do jedne krabicky s RPi

Nevyhody:

- musi se spravne nastavit UART v Raspberry Pi
- Linux neni real-time, takze pro half-duplex je potreba dobre resit DE/RE
- pro OSDP je vhodne otestovat casovani

Poznamka: pokud se pouzije transceiver s automatickym rizenim smeru, je software jednodussi. Pokud se smer ridi pres GPIO, je to kontrolovatelnejsi.

## Varianta B - USB-RS485 gateway

Alternativa:

```text
RPi USB
   |
   v
USB-UART bridge
   |
   v
RS-485 transceiver
```

Mozne bridge:

- CP2102N
- CH343
- FT232R / FT231X

Vyhody:

- na Linuxu se tvari jako `/dev/ttyUSBx`
- lze pouzit i s jinym pocitacem nez RPi
- mechanicky muze byt jako externi adapter

Nevyhody:

- porad je to USB vrstva navic
- je potreba vyresit DE/RE, typicky pres RTS nebo auto-direction
- pro embedded instalaci je HAT elegantnejsi

## Doporucena RPi Rev A

Pro prvni vlastni HW bych navrhl RPi HAT:

- 40pin Raspberry Pi header
- 3.3V RS-485 transceiver
- TVS ochrana na A/B, napr. SM712
- 120R terminace pres jumper
- bias odpory pres jumper
- svorkovnice RS485 A/B/GND
- volitelne svorkovnice pro rozvod VIN_BUS 12-48 V do sbernice
- LED TX/RX/POWER
- volitelne izolovana RS-485 jako Rev B

## Napajeni na sbernici

RPi gateway muze do kabelu posilat pouze komunikaci:

```text
A
B
GND
```

nebo i napajeni pro ctecky:

```text
VIN_BUS 12-48 V
GND
A
B
```

Pokud bude po stejnem kabelu napajeni vice ctecek, je vhodne:

- preferovat 24 V nebo 48 V kvuli ubytkum
- pojistit vetev
- pocitat proud vsech modulu
- zamek radeji napajet lokalne nebo zvlast, pokud ma velky proud

## OSDP dopad

RPi bude master / control panel. Ctecky budou periferie s adresami.

```text
RPi OSDP master
   |
   +-- reader 1, address 1
   +-- reader 2, address 2
   +-- reader 3, address 3
```

Na RPi strane tedy musi byt spolehliva RS-485 fyzicka vrstva a software, ktery umi OSDP nebo vlastni adresny protokol.

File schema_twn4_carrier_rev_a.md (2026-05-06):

# TWN4 Carrier Rev A - navrh schematu

Toto je prvni navrh elektrickeho schematu pro carrier desku k ELATEC TWN4 MultiTech 3 BLE. Neni to jeste vyrobni dokumentace, ale je to konkretni zapojeni, ktere se da prekreslit do KiCadu a dale overovat.

## Predpoklady

- Ctecka je TWN4 MultiTech 3 BLE.
- Komunikace se cteckou pujde pres `COM1_TX` / `COM1_RX`.
- Hlavni systemova komunikace bude RS-485, idealne OSDP.
- Napajeci vstup desky bude `12-48 V DC`, soucastky dimenzovat s rezervou aspon na `60 V`.
- Ctecka bude napajena z `5 V`.
- BLE varianta TWN4 pouziva interne `COM2` a `GPIO7`, proto se pro carrier nepouziji.
- Pro prvni revizi se pocita s neizolovanou RS-485. Izolovana verze muze byt Rev B.

## Blokove schema

```text
J1 VIN 12-48 V
   |
   +-- F1 pojistka / polyfuse
   +-- Q1 ochrana proti prepolovani
   +-- D1 TVS
   +-- filtr
   |
   +-- U1 buck 5 V
   |      |
   |      +-- TWN4 +5 V
   |      +-- rele 5 V
   |
   +-- U2 LDO 3.3 V
   |      |
   |      +-- RS-485 transceiver
   |      +-- I2C pull-upy / IO expander
   |
TWN4 X2
   |
   +-- COM1_TX/RX -> U3 RS-485
   +-- GPIO4 -> RS-485 DE/RE
   +-- GPIO5 -> rele driver
   +-- GPIO6 -> lock MOSFET driver
   +-- I2C -> volitelny IO expander
```

## Konektory

### J1 - napajeci vstup

```text
J1.1  VIN+   12-48 V DC
J1.2  GND
```

Doporucena svorkovnice: 2pin, roztec 3.5 mm nebo 5.08 mm podle proudu a mechaniky.

### J2 - RS-485 sbernice

```text
J2.1  RS485_A
J2.2  RS485_B
J2.3  GND / reference
J2.4  SHIELD optional
```

Poznamka: `SHIELD` nepripojovat natvrdo na logickou zem bez rozmyslu. Pro prvni revizi muze byt pres RC / jumper / chassis pad.

### J3 - rele vystup do dverni jednotky

```text
J3.1  RELAY_COM
J3.2  RELAY_NO
J3.3  RELAY_NC
```

Pouziti: bezpotencialovy impuls do existujici dverni jednotky.

### J4 - primy vystup pro zamek

```text
J4.1  LOCK+
J4.2  LOCK-
```

Navrh:

```text
LOCK+ = VIN_LOCK nebo VIN+
LOCK- = spinane pres N-MOSFET na GND
```

Pro prvni revizi doporucuji propojku:

```text
JP_LOCK_SUPPLY:
1-2 = LOCK+ napajeno z VIN+
2-3 = LOCK+ napajeno z externiho VIN_LOCK
```

### J5 - vstupy

```text
J5.1  DOOR_CONTACT
J5.2  REX_BUTTON
J5.3  TAMPER
J5.4  GND
```

Tyto vstupy je vhodne vest pres IO expander, aby se nespotrebovaly vsechny TWN4 GPIO.

### J6 - TWN4 X2 socket

Carrier deska ma mit 2x12 female socket, roztec 2.00 mm, protikus k TWN4 X2.

Relevantni piny:

```text
X2.3   I2C_SCL
X2.4   I2C_SDA
X2.10  HOSTSENSE
X2.12  GND
X2.13  UVCC / 5 V
X2.17  COM1_TX
X2.18  COM1_RX
X2.19  VCC 3.3 V reference z TWN4
X2.20  GPIO4
X2.21  GPIO5
X2.22  GPIO6
X2.23  PWRDWN-
X2.24  RESET-
```

`HOSTSENSE`:

- pro COM1 provoz musi byt low, tedy pripojeno na GND
- doporuceni: dat jumper `JP_HOSTSENSE`, aby slo volit COM1/USB rezim

```text
JP_HOSTSENSE:
1-2 = HOSTSENSE -> GND, COM1 mode
open = internal pull-up, USB mode
```

## Napajeci cast

### Vstupni ochrana

```text
J1 VIN+ -> F1 -> Q1 ideal diode / reverse polarity -> VIN_PROT
VIN_PROT -> D1 TVS -> GND
VIN_PROT -> Cbulk -> GND
```

Doporucene prvky:

- `F1`: vratna polyfuse nebo tavna pojistka podle ciloveho proudu
- `Q1`: P-MOSFET nebo ideal-diode/eFuse reseni pro ochranu proti prepolovani
- `D1`: TVS pro 48V system, napriklad rada SMBJ/SMCJ s vhodnym napetim
- `Cbulk`: elektrolyt nebo polymer, napr. 47-100 uF, napetove aspon 63 V
- `C_HF`: 100 nF + 1 uF keramika u menice

Poznamka: pro skutecny 48V/PoE svet je vhodne volit buck s maximalnim vstupem 80-100 V, ne pouze 60 V.

### 5V vetev

```text
VIN_PROT -> U1 wide-input buck -> +5V
```

Pozadavky:

- vstup aspon 60 V, lepe 80-100 V
- vystup 5 V
- proud minimalne 500 mA, lepe 1 A rezerva
- nizke EMI, dobra layout doporuceni podle datasheetu

Mozne typy:

- TI `LM5163` / `LM5164` family
- Analog Devices / Monolithic Power wide-input buck
- hotovy DC/DC modul s inputem vhodnym pro 48V systemy

`+5V` napaji:

- TWN4 pres X2.13 nebo odpovidajici 5V vstup
- rele civku, pokud bude 5V rele
- pripadne dalsi drobnou logiku

### 3.3V vetev

```text
+5V -> U2 LDO 3.3 V -> +3V3
```

`+3V3` napaji:

- RS-485 transceiver
- I2C pull-upy
- IO expander

Poznamka: TWN4 ma na X2.19 vlastni `VCC 3.3 V`. Nepouzivat ho jako hlavni zdroj pro carrier. Muze slouzit jako reference nebo pro kontrolu urovne.

## RS-485 cast

### U3 - RS-485 transceiver

Doporuceny typ:

- `THVD1450`, `MAX3485`, `SN65HVD1781` nebo podobny 3.3V/5V half-duplex RS-485 transceiver

Zapojeni:

```text
TWN4 COM1_TX -> U3 DI
TWN4 COM1_RX <- U3 RO
TWN4 GPIO4  -> U3 DE
TWN4 GPIO4  -> U3 /RE pres invertor nebo vhodne zapojeni
U3 A        -> RS485_A
U3 B        -> RS485_B
```

Jednoducha varianta:

```text
GPIO4 high = vysilani
GPIO4 low  = prijem
DE  = GPIO4
/RE = not GPIO4
```

Pokud nechceme pridavat invertor, lze zvazit:

```text
DE  = GPIO4
/RE = GPIO4
```

To ale pri vysilani vypne receiver a pri prijmu vypne driver. Chovani je pouzitelne, ale je potreba overit s firmware. Lepsi je maly invertor nebo tranzistor, aby bylo rizeni jasne.

Ochrany a sbernice:

```text
RS485_A -> TVS array -> GND
RS485_B -> TVS array -> GND
RS485_A <-> RS485_B pres 120 R, pouze pres jumper
bias pull-up / pull-down pouze pres jumper
```

Doporucene prvky:

- `D2`: ESD/TVS pro RS-485 linky, napr. `SM712`
- `RTERM`: 120 R pres `JP_TERM`
- `RBIAS_UP`, `RBIAS_DN`: napr. 680 R az 1.5 k podle navrhu sbernice, pres jumpery

## Rele vystup

### K1 - rele

```text
+5V -> K1 coil -> Q2 N-MOSFET/NPN -> GND
GPIO5 -> Rgate/Rbase -> Q2
D3 flyback pres civku
```

Kontakty:

```text
K1 COM -> J3.1
K1 NO  -> J3.2
K1 NC  -> J3.3
```

Doporuceni:

- signalove rele s civkou 5 V
- kontakty dimenzovat podle toho, jestli budou spinat jen signal, nebo i realnou zatez
- pokud ma rele spinat cizi system, drzet kontaktovou cast s rozumnymi izolačními mezerami

## Primy LOCK vystup

### Q3 - MOSFET low-side switch

```text
VIN_LOCK / VIN+ -> J4.1 LOCK+
J4.2 LOCK- -> drain Q3
source Q3 -> GND_POWER
GPIO6 -> Rgate -> gate Q3
gate -> Rpulldown -> GND
D4 / TVS / flyback ochrana pres zamek
```

Doporuceni:

- logic-level N-MOSFET
- napetova rezerva aspon 80-100 V pro 48V system
- proud podle ciloveho zamku, pro prototyp navrhnout treba 2 A
- samostatna pojistka `F_LOCK`
- siroke silove cesty
- zemni proud zamku vest oddelene od citlive logiky a spojit ve vhodnem bode

Poznamka: Pokud je vstup 48 V, primy vystup dava 48 V. Pro 12V zamek je potreba bud 12V vstup, externi 12V napajeni zamku, nebo dalsi menic 48 -> 12 V.

## Vstupy pres IO expander

Protoze TWN4 ma na X2 pro vlastni pouziti pohodlne hlavne GPIO4-6, je vhodne pouzit I2C IO expander.

### U4 - MCP23008 / MCP23017

```text
TWN4 I2C_SCL -> U4 SCL
TWN4 I2C_SDA -> U4 SDA
SCL -> 4.7 k -> +3V3
SDA -> 4.7 k -> +3V3
U4 VDD -> +3V3
U4 GND -> GND
```

Vstupy:

```text
J5 DOOR_CONTACT -> ochrana/filter -> U4 GP0
J5 REX_BUTTON   -> ochrana/filter -> U4 GP1
J5 TAMPER       -> ochrana/filter -> U4 GP2
```

Vystupy / rezervy:

```text
U4 GP3 -> LED status optional
U4 GP4 -> reserve
U4 GP5 -> reserve
U4 GP6 -> reserve
U4 GP7 -> reserve
```

Poznamka: Pokud nechceme v prvni firmware iteraci resit I2C expander, lze vstupy v Rev A neosadit nebo je vyvest pouze na test konektor.

## Signalove prirazeni TWN4 GPIO

Minimalni varianta bez IO expanderu:

```text
GPIO4 = RS485_DIR
GPIO5 = RELAY_CTRL
GPIO6 = LOCK_CTRL
```

Varianta s IO expanderem:

```text
GPIO4 = RS485_DIR
GPIO5 = RELAY_CTRL
GPIO6 = LOCK_CTRL
I2C   = DOOR / REX / TAMPER / dalsi IO
```

## Netlist - hlavni signaly

```text
VIN_IN       J1.1 -> F1 -> Q1 -> VIN_PROT
GND          J1.2, U1.GND, U2.GND, TWN4.GND, U3.GND
+5V          U1.OUT -> TWN4.X2.13, K1.COIL, U2.IN
+3V3         U2.OUT -> U3.VCC, U4.VDD, I2C pull-upy

TWN4_COM1_TX TWN4.X2.17 -> U3.DI
TWN4_COM1_RX TWN4.X2.18 <- U3.RO
RS485_DIR    TWN4.X2.20 -> U3.DE / U3.RE_CTRL
RS485_A      U3.A -> D2 -> J2.1
RS485_B      U3.B -> D2 -> J2.2

RELAY_CTRL   TWN4.X2.21 -> Q2.GATE
LOCK_CTRL    TWN4.X2.22 -> Q3.GATE

I2C_SCL      TWN4.X2.3 -> U4.SCL
I2C_SDA      TWN4.X2.4 -> U4.SDA
```

## Orientacni BOM

| Ref | Funkce | Priklad |
| --- | --- | --- |
| J1 | VIN vstup | 2pin svorkovnice |
| J2 | RS-485 | 3/4pin svorkovnice |
| J3 | rele kontakt | 3pin svorkovnice |
| J4 | lock vystup | 2pin svorkovnice |
| J6 | TWN4 X2 socket | 2x12, 2.00 mm female socket |
| F1 | vstupni pojistka | podle proudu |
| D1 | vstupni TVS | 48V system, SMBJ/SMCJ rada |
| U1 | 5V buck | wide-input 60-100 V |
| U2 | 3.3V LDO | 300 mA LDO |
| U3 | RS-485 | THVD1450 / MAX3485 / SN65HVD1781 |
| D2 | RS-485 TVS | SM712 nebo ekvivalent |
| K1 | rele | 5V signal/power relay |
| Q2 | rele driver | maly N-MOSFET nebo NPN |
| Q3 | lock driver | logic-level N-MOSFET 80-100 V |
| U4 | IO expander | MCP23008 / MCP23017 |

## Veci k overeni pred kreslenim PCB

1. Fyzicky stav X2 na konkretni ctecce: osazeny pin header, nebo jen pady?
2. Presny protikus konektoru a vyska mezi deskami.
3. Kde je BLE antena a kolik keepout prostoru potrebuje.
4. Jestli TWN4 COM1 signaly opravdu potrebuji inverzi kvuli popisu "low active TTL".
5. Maximalni proud zamku.
6. Jestli lock vystup ma spinat VIN, nebo ma byt na desce samostatny 12V menic.
7. Jestli bude prvni deska podporovat jen DC 12-48 V, nebo rovnou i PoE 802.3af/at.
8. OSDP firmware: zda bude smer RS-485 rizen z GPIO4, nebo se pouzije transceiver s auto-direction.

## Doporuceni pro Rev A

Pro prvni desku bych vyrobil neizolovanou verzi:

- X2 socket pro TWN4
- 12-48 V vstup, soucastky s rezervou
- 5V buck pro TWN4
- 3.3V logika pro transceiver
- RS-485 s TVS, terminaci a bias jumpery
- GPIO4 jako RS-485 direction
- GPIO5 rele
- GPIO6 lock MOSFET
- I2C expander pripraveny pro DOOR/REX/TAMPER, klidne jako optional osazeni

Tato revize overi mechaniku, napajeni, RS-485/OSDP a zakladni dverni vystupy.

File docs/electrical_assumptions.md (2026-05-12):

# Electrical Assumptions

## Power

ASSUMPTION: Input is 12 V to 48 V nominal.

ASSUMPTION: The 5 V rail should be designed for at least 500 mA continuous reserve, preferably up to 1 A class because the LM5164 candidate supports a 1 A output class.

ASSUMPTION: Lock power is switched from protected input voltage, not generated from the 5 V rail.

## TWN4

ASSUMPTION: TWN4 MultiTech 3 BLE is powered from 5 V on X2/UVCC.

ASSUMPTION: TWN4 COM1 TX/RX low-active TTL behavior must be verified on scope before final release.

ASSUMPTION: COM2/GPIO7 are left alone for BLE module compatibility.

## RS-485

ASSUMPTION: OSDP is half-duplex and one transceiver direction signal can drive both `DE` and `RE#`.

ASSUMPTION: Only one bus end should have termination and bias enabled.

## Door IO

ASSUMPTION: Door/REX/tamper/AUX inputs are dry-contact style inputs with local pull network, RC filtering and ESD protection.

## Mechanical TODO

- Exact TWN4 X2 pin coordinate.
- Mating connector height.
- Standoff height.
- Mounting hole positions.
- Reader keep-out area.

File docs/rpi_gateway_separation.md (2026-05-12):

# RPi Gateway Separation

Rev E compact carrier intentionally excludes the Raspberry Pi gateway hardware from the TWN4 carrier PCB.

## Reason

The TWN4 carrier and the RPi gateway have different mechanical and electrical roles:

- TWN4 carrier lives at the reader/door side.
- RPi gateway lives at the controller side.
- TWN4 carrier handles reader power, local I/O, lock/relay, and RS-485 bus connection.
- RPi gateway handles Raspberry Pi UART/USB interface and RS-485 master/control-panel role.

Keeping them separate makes the first hardware bring-up easier and avoids making the door-side carrier unnecessarily large.

## Rev E impact

- Rev E PCB contains the compact TWN4 carrier only.
- RPi gateway footprints inherited from older broad concepts are not placed on the compact Rev E PCB.
- A dedicated RPi gateway schematic/PCB should be created as its own revision path.

## Recommended RPi gateway Rev A

- Raspberry Pi 40-pin header or USB interface, depending on selected gateway style.
- 3.3 V RS-485 transceiver.
- SM712 or equivalent RS-485 TVS protection.
- Optional 120 ohm termination jumper.
- Optional bias jumper.
- A/B/GND connector.
- Optional VIN_BUS distribution connector.
- TX/RX/power LEDs.

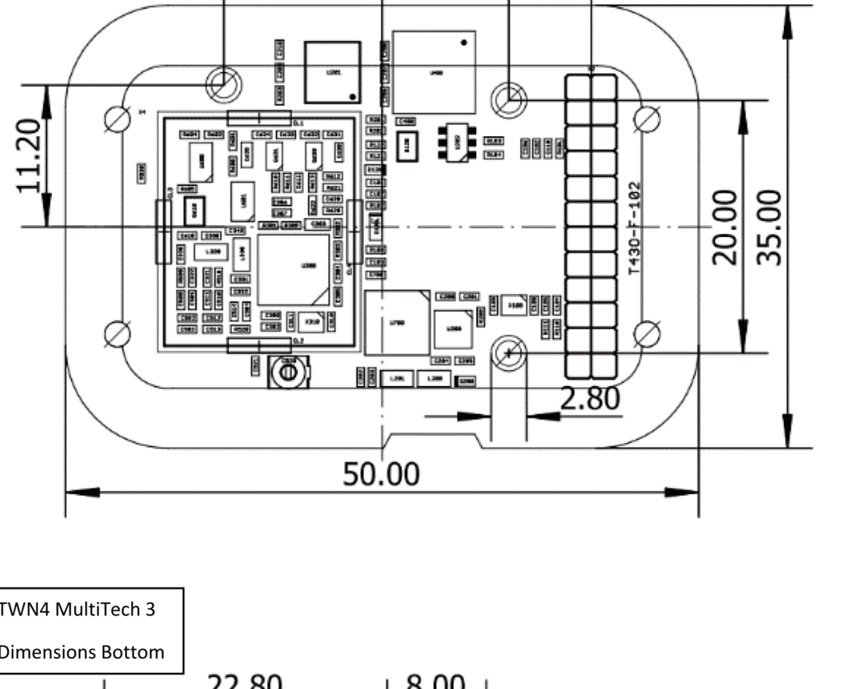
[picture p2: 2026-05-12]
docs/mechanical_extract/top_dimensions_crop.png

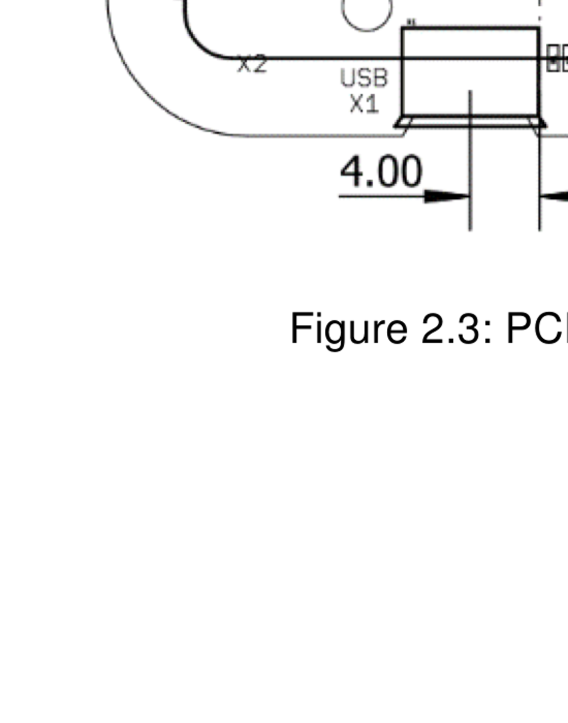
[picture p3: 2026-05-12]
docs/mechanical_extract/bottom_x2_area_crop.png

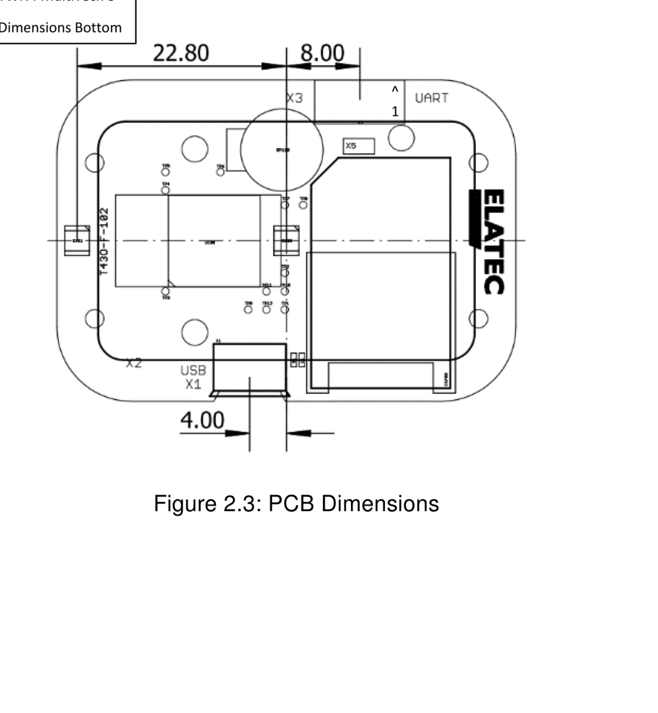
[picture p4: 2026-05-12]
docs/mechanical_extract/bottom_dimensions_crop.png

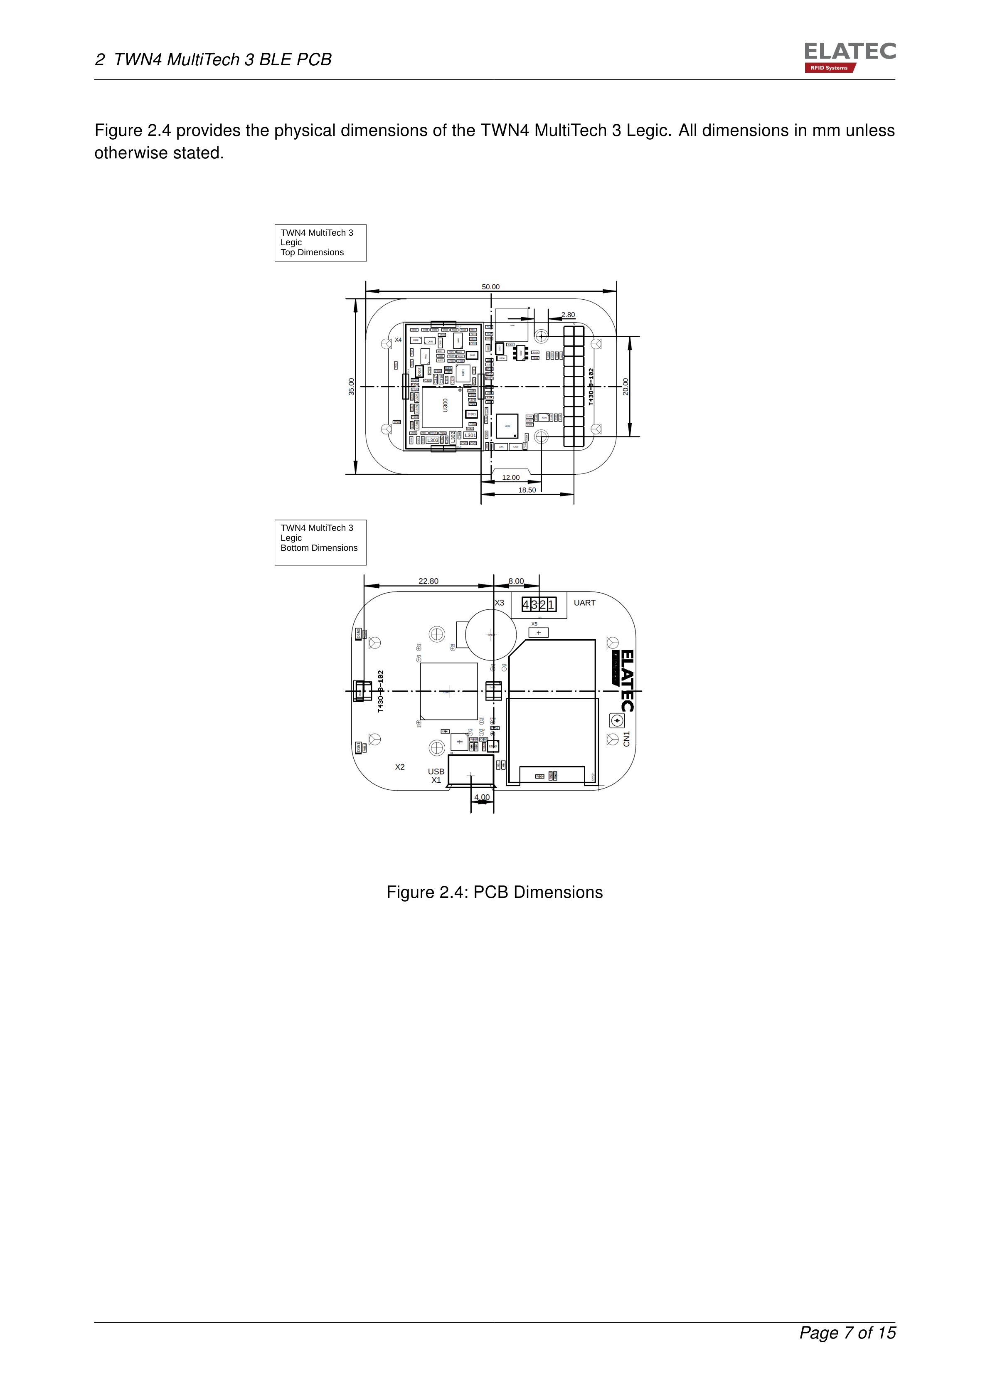
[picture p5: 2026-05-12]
docs/mechanical_extract/docrev10_page_07.png

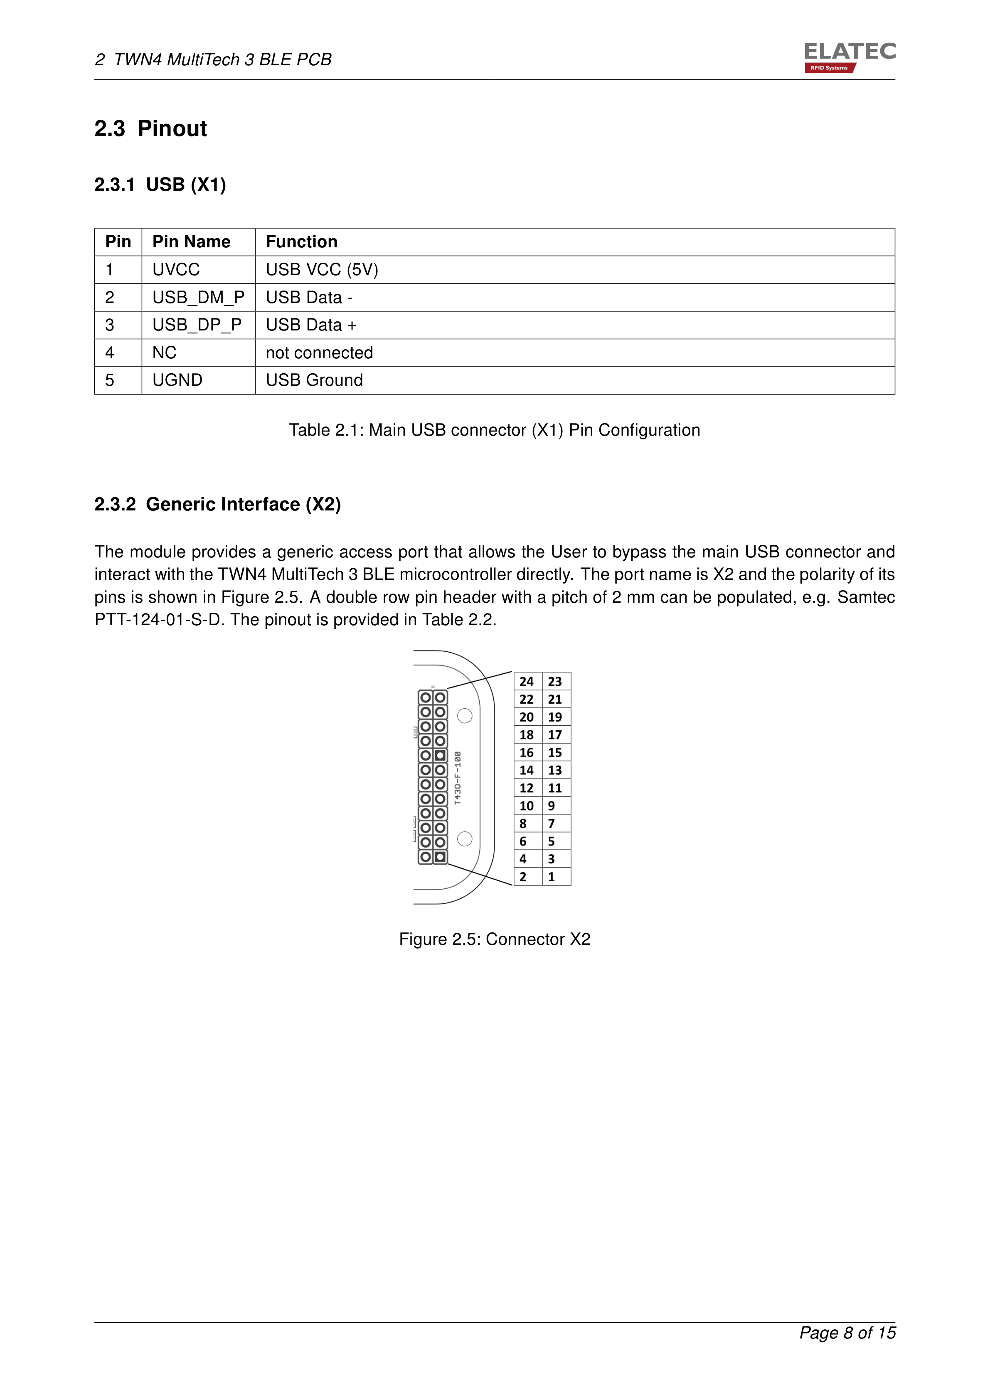
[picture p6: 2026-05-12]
docs/mechanical_extract/docrev10_page_08.png

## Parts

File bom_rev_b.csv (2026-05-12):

Ref | Qty | Value / Part | Description | Notes
J1 | 1 | 2-pin 5.08mm terminal | VIN 12-48V input | Choose current rating by installation
J2 | 1 | 4-pin 5.08mm terminal | RS-485 A/B/GND/SHIELD reader-side bus
J3 | 1 | 3-pin 5.08mm terminal | Relay COM/NO/NC output
J4 | 1 | 2-pin 5.08mm terminal | Direct lock output
J5 | 1 | 4-pin 3.5mm terminal | Door/REX/Tamper inputs
J6 | 1 | 2x12 2.00mm female socket | TWN4 X2 socket | Samtec PTF-124-01-S-D or compatible candidate
J10 | 1 | 2x20 2.54mm header | Raspberry Pi 40-pin header
J11 | 1 | 4-pin 5.08mm terminal | RPi RS-485/VIN bus output
J12 | 1 | 2-pin 5.08mm terminal | RPi VIN_BUS input
U1 | 1 | LTC4367 | 100V UV/OV/reverse supply protection controller | Front-end protection candidate; divider values final TBD
Q1A/Q1B | 2 | 100V N-MOSFET | Back-to-back protection FETs for U1 | Select by bus current and SOA
D1 | 1 | SMBJ58A | VIN TVS for 48V-class input | Final value depends on front-end limits
F1 | 1 | 1.1-1.5A 60V+ fuse/polyfuse | VIN logic protection | Use higher rating if lock current passes this path
U2 | 1 | LM5164 | 100V input 1A synchronous buck | 5V rail
CIN1/CIN2 | 2 | 2.2uF 100V X7R | LM5164 input capacitors | Place close to U2
CIN_BULK | 1 | 47uF 100V | VIN bulk capacitor
L1 | 1 | 68uH Isat >1.8A | Buck inductor | Low DCR
COUT1/COUT2 | 2 | 22uF 25V X7R | 5V output capacitors
RFB_TOP | 1 | 453k 1% | LM5164 feedback top | From TI 5V example
RFB_BOT | 1 | 49.9k 1% | LM5164 feedback bottom | From TI 5V example
RRON | 1 | 100k 1% | LM5164 RON resistor | From TI 5V example
RA | 1 | 453k 1% | LM5164 ripple injection network | From TI 5V example
CA | 1 | 3.3nF | LM5164 ripple injection network | From TI 5V example
CB | 1 | 56pF | LM5164 ripple injection network | From TI 5V example
CBST | 1 | 2.2nF 50V | LM5164 bootstrap capacitor | From TI 5V example
U3 | 1 | TLV75533PDBVR | 3.3V LDO | Or equivalent
C3_IN/C3_OUT | 2 | 1uF 10V | LDO capacitors
U4 | 1 | THVD1450 | Reader-side RS-485 transceiver | 3.3V supply
U10 | 1 | THVD1450 | RPi-side RS-485 transceiver | 3.3V supply
D2/D10 | 2 | CDSOT23-SM712 | RS-485 TVS diode array | One on each board
R_TX/R_RX/R10/R11 | 4 | 33R | UART series resistors
R_DIR/R12 | 2 | 100R | RS-485 direction gate/logic series resistors
R_DIR_PD/R13 | 2 | 100k | RS-485 receive-default pulldowns
R_A_SER/R_B_SER/R14/R15 | 4 | 10R | RS-485 bus series resistors
R_TERM/R16 | 2 | 120R | RS-485 termination | Enable by jumper only at bus ends
R_BIAS_UP/R17 | 2 | 680R | RS-485 pull-up bias | Usually populate on master only
R_BIAS_DN/R18 | 2 | 680R | RS-485 pull-down bias | Usually populate on master only
K1 | 1 | Omron G5V-2 DC5 | 5V DPDT signal relay candidate | Use one COM/NO/NC contact
Q2 | 1 | 2N7002 | Relay low-side driver
D3 | 1 | 1N4148 or SS14 | Relay flyback diode
R_G2 | 1 | 100R | Relay gate resistor
R_PD2 | 1 | 100k | Relay gate pulldown
Q3 | 1 | DMT10H015LSS or similar | 100V logic-level N-MOSFET for lock output | Must specify Rds(on) at Vgs=4.5V
U6 | 1 | SN74AHCT1G125 | 5V gate buffer for lock MOSFET | TTL-compatible input from 3.3V GPIO
R_G3 | 1 | 47R | Lock MOSFET gate resistor
R_PD3 | 1 | 100k | Lock MOSFET gate pulldown
F_LOCK | 1 | TBD | Lock output fuse | Choose by lock current
D4 | 1 | TBD | Lock flyback diode | Choose by lock voltage/current
D5 | 1 | TBD | Lock TVS | Choose by 12/24/48V lock variant
U5 | 1 | MCP23008 | 8-bit I2C GPIO expander | Door/REX/Tamper inputs
R_SCL_PULL/R_SDA_PULL | 2 | 4.7k | I2C pull-ups to 3.3V
R_SCL_SER/R_SDA_SER | 2 | 33R | I2C series resistors
R_RESET | 1 | 10k | MCP23008 reset pull-up
R_IN_SERx | 4 | 1k | Input series resistors | Door/REX/Tamper/AUX
R_IN_PULLx | 4 | 10k | Input pull-ups to 3.3V
C_INx | 4 | 100nF | Input debounce/filter capacitors
LED_PWR/LED_TX/LED_RELAY/LED_LOCK | 4 | LED | Diagnostic LEDs
R_LEDx | 4 | 2.2k | LED resistors

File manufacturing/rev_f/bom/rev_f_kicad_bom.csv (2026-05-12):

Refs | Value | Footprint | Qty | DNP
C1 | 4.7uF 100V X7R input bulk | Capacitor_SMD:C_1210_3225Metric | 1
C2 | 100nF 100V input HF | Capacitor_SMD:C_0805_2012Metric | 1
C3 | 100nF BST | Capacitor_SMD:C_0603_1608Metric | 1
C4 | 22uF 100V buck input | Capacitor_SMD:C_1210_3225Metric | 1
C5 | 47uF 10V buck output | Capacitor_SMD:C_1210_3225Metric | 1
C6 | 100nF 5V HF | Capacitor_SMD:C_0603_1608Metric | 1
C7 | 1uF 3V3 LDO in | Capacitor_SMD:C_0603_1608Metric | 1
C8 | 1uF 3V3 LDO out | Capacitor_SMD:C_0603_1608Metric | 1
C36 | 10nF DOOR_IN filter | Capacitor_SMD:C_0603_1608Metric | 1
C37 | 10nF REX_IN filter | Capacitor_SMD:C_0603_1608Metric | 1
C38 | 10nF TAMPER_IN filter | Capacitor_SMD:C_0603_1608Metric | 1
C39 | 10nF AUX_IN filter | Capacitor_SMD:C_0603_1608Metric | 1
D1 | SM712 RS-485 TVS | Package_TO_SOT_SMD:SOT-23 | 1
D2 | Lock flyback diode/TVS placeholder | Diode_SMD:D_SMA | 1
D3 | RPi side SM712 TVS | Package_TO_SOT_SMD:SOT-23 | 1
D4 | SMBJ58A input TVS | Diode_SMD:D_SMB | 1
D5 | Relay flyback diode | Diode_SMD:D_SOD-123 | 1
F1 | 1.5A 60V+ fuse/PTC | Fuse:Fuse_1206_3216Metric | 1
J1 | VIN 12-48V IN | TerminalBlock_Phoenix:TerminalBlock_Phoenix_PT-1,5-2-3.5-H_1x02_P3.50mm_Horizontal | 1
J2 | TWN4 MultiTech 3 BLE X2 socket | Connector_PinSocket_2.00mm:PinSocket_2x12_P2.00mm_Vertical | 1
J3 | RS-485 OUT A/B/+VIN/GND | TerminalBlock_Phoenix:TerminalBlock_Phoenix_PT-1,5-4-3.5-H_1x04_P3.50mm_Horizontal | 1
J4 | Relay contact COM/NC/NO | TerminalBlock_Phoenix:TerminalBlock_Phoenix_PT-1,5-3-3.5-H_1x03_P3.50mm_Horizontal | 1
J5 | LOCK OUT +VIN/SW- | TerminalBlock_Phoenix:TerminalBlock_Phoenix_PT-1,5-2-3.5-H_1x02_P3.50mm_Horizontal | 1
J6 | DOOR/REX/TAMPER/AUX inputs | TerminalBlock_Phoenix:TerminalBlock_Phoenix_PT-1,5-6-3.5-H_1x06_P3.50mm_Horizontal | 1
J7 | RPi 40-pin header subset | Connector_PinHeader_2.54mm:PinHeader_2x20_P2.54mm_Vertical | 1
J8 | RPi RS-485 BUS A/B/+VIN/GND | TerminalBlock_Phoenix:TerminalBlock_Phoenix_PT-1,5-4-3.5-H_1x04_P3.50mm_Horizontal | 1
JP1 | LOCK SERVICE LINK | Jumper:SolderJumper-2_P1.3mm_Open_Pad1.0x1.5mm | 1
K1 | Dry relay contact NO/NC/COM | Relay_THT:Relay_SPDT_Omron_G5V-1 | 1
L1 | 47uH shielded inductor | Inductor_SMD:L_Bourns-SRN1060 | 1
Q1 | Reverse/surge FET A 100V | Package_SO:SOIC-8_3.9x4.9mm_P1.27mm | 1
Q2 | Reverse/surge FET B 100V | Package_SO:SOIC-8_3.9x4.9mm_P1.27mm | 1
Q3 | Relay low-side driver | Package_TO_SOT_SMD:SOT-23 | 1
Q4 | Lock low-side MOSFET 100V | Package_SO:SOIC-8_3.9x4.9mm_P1.27mm | 1
R1 | 1M UV/OV top placeholder | Resistor_SMD:R_0603_1608Metric | 1
R2 | 100k UV/OV mid placeholder | Resistor_SMD:R_0603_1608Metric | 1
R3 | 27k UV/OV bottom placeholder | Resistor_SMD:R_0603_1608Metric | 1
R4 | 200k LM5164 RON | Resistor_SMD:R_0603_1608Metric | 1
R5 | 604k 5V FB top | Resistor_SMD:R_0603_1608Metric | 1
R6 | 100k 5V FB bottom | Resistor_SMD:R_0603_1608Metric | 1
R7 | 120R RS485 TERM DNP/JMP | Resistor_SMD:R_0603_1608Metric | 1 | DNP
R8 | 680R RS485 bias pullup DNP/JMP | Resistor_SMD:R_0603_1608Metric | 1 | DNP
R9 | 680R RS485 bias pulldown DNP/JMP | Resistor_SMD:R_0603_1608Metric | 1 | DNP
R10 | 22R RS485 A series option | Resistor_SMD:R_0603_1608Metric | 1
R11 | 22R RS485 B series option | Resistor_SMD:R_0603_1608Metric | 1
R12 | 100R relay gate | Resistor_SMD:R_0603_1608Metric | 1
R13 | 100k relay gate pulldown | Resistor_SMD:R_0603_1608Metric | 1
R14 | 100R lock gate | Resistor_SMD:R_0603_1608Metric | 1
R15 | 100k lock gate pulldown | Resistor_SMD:R_0603_1608Metric | 1
R16 | 10k DOOR_IN pullup | Resistor_SMD:R_0603_1608Metric | 1
R17 | 10k REX_IN pullup | Resistor_SMD:R_0603_1608Metric | 1
R18 | 10k TAMPER_IN pullup | Resistor_SMD:R_0603_1608Metric | 1
R19 | 10k AUX_IN pullup | Resistor_SMD:R_0603_1608Metric | 1
R20 | 120R RPi RS485 TERM DNP/JMP | Resistor_SMD:R_0603_1608Metric | 1 | DNP
R21 | 680R RPi bias pullup DNP/JMP | Resistor_SMD:R_0603_1608Metric | 1 | DNP
R22 | 680R RPi bias pulldown DNP/JMP | Resistor_SMD:R_0603_1608Metric | 1 | DNP
TP1 | VIN_IN | TestPoint:TestPoint_Pad_D1.5mm | 1
TP2 | VIN_PROT | TestPoint:TestPoint_Pad_D1.5mm | 1
TP3 | +5V | TestPoint:TestPoint_Pad_D1.5mm | 1
TP4 | +3V3 | TestPoint:TestPoint_Pad_D1.5mm | 1
TP5 | GND | TestPoint:TestPoint_Pad_D1.5mm | 1
TP6 | COM1_TX | TestPoint:TestPoint_Pad_D1.5mm | 1
TP7 | COM1_RX | TestPoint:TestPoint_Pad_D1.5mm | 1
TP8 | GPIO4_RS485_DIR | TestPoint:TestPoint_Pad_D1.5mm | 1
TP9 | RS485_A | TestPoint:TestPoint_Pad_D1.5mm | 1
TP10 | RS485_B | TestPoint:TestPoint_Pad_D1.5mm | 1
TP11 | LOCK_GATE_5V | TestPoint:TestPoint_Pad_D1.5mm | 1
TP12 | LOCK_SW_LOW | TestPoint:TestPoint_Pad_D1.5mm | 1
TP13 | RELAY_COIL_LOW | TestPoint:TestPoint_Pad_D1.5mm | 1
TP14 | DOOR_IN | TestPoint:TestPoint_Pad_D1.5mm | 1
TP15 | REX_IN | TestPoint:TestPoint_Pad_D1.5mm | 1
TP16 | TAMPER_IN | TestPoint:TestPoint_Pad_D1.5mm | 1
TP17 | AUX_IN | TestPoint:TestPoint_Pad_D1.5mm | 1
TP18 | RPI_RS485_A | TestPoint:TestPoint_Pad_D1.5mm | 1
TP19 | RPI_RS485_B | TestPoint:TestPoint_Pad_D1.5mm | 1
TP20 | RPI_RS485_DIR | TestPoint:TestPoint_Pad_D1.5mm | 1
U1 | LTC4367 surge/OV/UV protector | Package_SO:MSOP-8_3x3mm_P0.65mm | 1
U2 | LM5164 12-48V to 5V buck | Package_SO:Texas_HSOP-8-1EP_3.9x4.9mm_P1.27mm | 1
U3 | TLV75533 3.3V local rail | Package_TO_SOT_SMD:SOT-23-5 | 1
U4 | THVD1450 reader RS-485 transceiver | Package_SO:SOIC-8_3.9x4.9mm_P1.27mm | 1
U5 | 5V gate buffer for lock FET | Package_TO_SOT_SMD:SOT-23-5 | 1
U6 | MCP23008 door input expander | Package_SO:SOIC-18W_7.5x11.6mm_P1.27mm | 1
U7 | RPi RS-485 transceiver | Package_SO:SOIC-8_3.9x4.9mm_P1.27mm | 1

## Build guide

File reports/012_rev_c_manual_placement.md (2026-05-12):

# 012 Rev C Manual Placement

Date: 2026-05-08

## What Changed

- Created a new PCB variant:
  - `kicad/twn4_access_system/twn4_access_system_rev_c_manual_placement.kicad_pcb`
- Kept the routed Freerouting Rev C board untouched:
  - `kicad/twn4_access_system/twn4_access_system_rev_c.kicad_pcb`
- Removed autorouted copper from the manual-placement variant.
- Re-arranged footprints into more meaningful functional blocks:
  - power input/protection/buck in the upper-left area,
  - TWN4 X2 connector in the carrier area,
  - RS-485 transceiver, TVS and field connector near each other,
  - relay/lock/output section separated from low-level logic,
  - input section near field connector,
  - Raspberry Pi gateway section isolated as an optional lower block,
  - testpoints grouped into a service column.

## Why

The first routed Rev C proved that the KiCad -> DSN -> Freerouting -> SES -> KiCad workflow works and can produce a DRC-clean board. However, the placement was not electrically or mechanically sensible.

This new manual-placement variant is a better basis for a second routing pass.

## Verification

DRC report:

- `reports/rev_c_manual_placement_drc.rpt`

Result:

- DRC violations: 0
- Unconnected pads/items: 164

This is expected because the manual-placement board is intentionally unrouted.

Preview:

- `manufacturing/rev_c/rev_c_manual_placement_preview.pdf`

## Assumptions

ASSUMPTION: This is still a service prototype, not a compact final carrier outline.

ASSUMPTION: TWN4 X2 final mechanical alignment is still not verified, so this placement is electrically grouped but not mechanically final.

ASSUMPTION: The next DSN export should be done from this manual-placement board, not from the previous automatically placed board.

## Next Step

Open `twn4_access_system_rev_c_manual_placement.kicad_pcb` in KiCad 9, export Specctra DSN, run Freerouting again, import SES, then run DRC.

The expected improvement is not just a DRC-clean route, but a route based on more sensible component placement.

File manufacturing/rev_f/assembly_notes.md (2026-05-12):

# Rev F Assembly Notes

Rev F should not be assembled as a production candidate until the buck and lock/relay routing has been manually cleaned.

If a PCB is made only as a fit/bring-up experiment:

1. Assemble no lock load on first build.
2. Bring up VIN to 5 V with current limit.
3. Measure buck temperature and ripple before installing TWN4.
4. Install TWN4 only after stable 5 V is confirmed.
5. Test RS-485 locally before connecting long cable runs.
6. Test relay/lock output with dummy load before a real lock.

Do not connect a real door lock until copper width, connector current, MOSFET dissipation, and inductive protection are reviewed.

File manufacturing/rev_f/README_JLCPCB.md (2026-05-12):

# Rev F JLCPCB Draft Package

Rev F is an audit checkpoint generated from Rev E. It is DRC clean and has manufacturing draft outputs, but it is not order-approved.

## Files

- Gerbers: `manufacturing/rev_f/gerbers`
- JLCPCB upload draft subset: `manufacturing/rev_f/jlcpcb_upload_draft`
- Drill: `manufacturing/rev_f/drill`
- BOM: `manufacturing/rev_f/bom/rev_f_kicad_bom.csv`
- CPL: `manufacturing/rev_f/pick_place/rev_f_cpl.csv`
- DRC: `reports/rev_f_power_cleanup_drc.rpt`
- Preview PDF: `manufacturing/rev_f/rev_f_compact_power_cleanup_preview.pdf`

## Current status

- KiCad DRC: clean.
- Manufacturing draft files: generated.
- Order approval: blocked.

## Production blocker

The Rev E autorouter topology cannot be safely upgraded by globally widening power tracks. Rev F must receive a manual buck and lock/relay reroute before ordering.

## Upload note

The `jlcpcb_upload_draft` folder can be used to test JLCPCB import, layer recognition, and board outline only. Do not order from this folder as a final hardware release.

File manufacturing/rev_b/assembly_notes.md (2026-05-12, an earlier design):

# Rev B Assembly Notes

## Assembly Intent

First prototype should favor serviceability over compactness.

## Likely Manual or Special-Review Parts

- TWN4 X2 mating connector until exact Samtec/JLCPCB-compatible part is locked.
- High-voltage/protection MOSFETs if selected footprint is not in JLCPCB basic/extended library.
- Terminal blocks if exact color/orientation is important.
- Relay if not available through JLCPCB assembly.

## Polarity-Sensitive Parts

- Input TVS
- RS-485 SM712
- Lock flyback diode / TVS
- Buck regulator
- LDO
- MOSFETs
- Relay coil diode

## Assembly Checks

- Confirm no solder bridges on TWN4 X2 connector.
- Confirm terminal block orientation.
- Confirm relay pinout.
- Confirm MOSFET pinout against final selected part.
- Confirm SM712 orientation and A/B/GND connection.

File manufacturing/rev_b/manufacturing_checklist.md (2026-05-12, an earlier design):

# Rev B Manufacturing Checklist

## Schematic

- [x] ERC run
- [x] ERC has no error-severity findings
- [x] Netlist exports
- [x] BOM exports
- [x] Testpoints added to schematic
- [ ] All symbols migrated to stable project/library symbols
- [ ] All support values reviewed against datasheets
- [ ] All configuration nets intentionally resolved or documented

## PCB

- [ ] PCB layout created
- [ ] Board outline defined
- [ ] Mounting holes defined
- [ ] TWN4 X2 mechanical placement verified
- [ ] Buck layout reviewed
- [ ] RS-485 protection close to connector
- [ ] Lock current path reviewed
- [ ] DRC clean
- [ ] Silkscreen reviewed

## JLCPCB Outputs

- [ ] Gerbers generated
- [ ] Drill files generated
- [ ] CPL / Pick and Place generated
- [ ] BOM mapped to final MPN/LCSC parts
- [ ] Hand-solder parts listed
- [ ] Gerbers opened in viewer

## Electrical Before Order

- [ ] COM1 polarity verified on scope
- [ ] Lock current target known
- [ ] Input transient/TVS selection reviewed
- [ ] RS-485 A/B convention checked
- [ ] Termination/bias defaults selected
- [ ] Galvanic isolation deferral accepted for Rev B

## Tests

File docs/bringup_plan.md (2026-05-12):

# Bring-Up Plan

## 1. Bare PCB Inspection

- Inspect solder mask, drill registration and silkscreen.
- Check polarity markings.
- Check connector orientation.
- Check there are no visible copper shorts.

## 2. Resistance Checks

- Measure VIN to GND.
- Measure 5 V to GND.
- Measure 3.3 V to GND.
- Measure RS485_A to RS485_B.
- Verify termination jumper state before applying power.

## 3. First Power

- Use a bench supply with current limit.
- Start at 12 V input.
- Current limit initially low.
- Power without TWN4 installed.
- Confirm 5 V rail.
- Confirm 3.3 V rail if fitted.

## 4. TWN4 Power Test

- Install TWN4.
- Power at 12 V with current limit.
- Measure 5 V at TWN4 connector.
- Check for reset/brownout behavior.

## 5. UART / RS-485 Test

- Probe COM1 TX/RX polarity.
- Probe DE/RE.
- Check RS-485 A/B idle level.
- Test OSDP traffic at low baud first.

## 6. Inputs

- Test each dry-contact input.
- Confirm input filtering delay is acceptable.
- Confirm no false triggers during RS-485 traffic and relay switching.

## 7. Relay

- Switch relay without external load.
- Measure coil current.
- Confirm flyback suppression behavior.

## 8. Lock Output

- Test lock output with no load.
- Test with dummy load and current limit.
- Test with real lock only after dummy-load behavior is clean.

## 9. Record Results

Create a bench log with:

- supply voltage,
- current draw,
- measured rails,
- thermal observations,
- scope screenshots of RS-485 and lock switching,
- firmware version.

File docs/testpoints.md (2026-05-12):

# Testpoints

## Required Power Testpoints

- TP_VIN_IN
- TP_VIN_PROT
- TP_5V
- TP_3V3
- TP_GND, multiple points

## Required TWN4 / UART Testpoints

- TP_COM1_TX
- TP_COM1_RX
- TP_GPIO4_RS485_DIR
- TP_HOSTSENSE

## Required RS-485 Testpoints

- TP_RS485_A
- TP_RS485_B
- TP_DE_RE
- TP_TX
- TP_RX
- TP_GND_NEAR_BUS

## Required Lock / Relay Testpoints

- TP_LOCK_GATE
- TP_LOCK_SW_LOW
- TP_RELAY_COIL_LOW
- TP_RELAY_COM
- TP_RELAY_NO
- TP_RELAY_NC

## Required Input Testpoints

- TP_DOOR_IN
- TP_REX_IN
- TP_TAMPER_IN
- TP_AUX_IN

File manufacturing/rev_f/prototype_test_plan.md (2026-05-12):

# Rev F Prototype Test Plan

## Goal

Rev F is primarily a layout audit checkpoint. Testing should focus on validating assumptions before committing to a manual final reroute.

## Checks before ordering any PCB

- Open Gerbers in a viewer.
- Confirm JLCPCB recognizes outline and copper layers.
- Inspect buck area around U2/L1/C4/C5/C6.
- Inspect lock path around J5/D2/Q4.
- Inspect relay path around K1/Q3/D5.
- Confirm X2 mechanical location with a 1:1 print or test coupon.

## Bring-up if fabricated as a fit prototype

- Visual inspection.
- Continuity checks: VIN/GND, 5V/GND, LOCK_SW_LOW/GND.
- Power at 12 V with current limit.
- Verify 5 V without TWN4.
- Verify 5 V with TWN4.
- Test RS-485 short cable only.
- Test lock output with dummy load only.

## Data to record

- VIN voltage.
- 5 V voltage and ripple.
- Idle current.
- TWN4 current.
- Lock dummy-load current.
- Buck temperature.
- MOSFET/relay/connector temperature.
- Mechanical mismatch notes.

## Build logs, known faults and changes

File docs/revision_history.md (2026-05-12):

# Revision History

## Rev A

Concept documentation and initial KiCad concept sheet.

## Rev B

Working production-prototype direction.

Current Rev B status:

- KiCad schematic draft exists.
- Netlist export works.
- Reports and manufacturing folder scaffold exist.
- PCB layout is not complete.
- JLCPCB package is not ready for ordering.

## Planned Rev C

Rev C engineering preview was created to close the Rev B file-output gap:

- PCB file created: `kicad/twn4_access_system/twn4_access_system_rev_c.kicad_pcb`
- Gerbers exported
- Drill file exported
- CPL exported
- BOM copied/exported into Rev C manufacturing folder
- DRC report created

Current Rev C status:

- placed but not routed
- DRC not clean because of unconnected pads/items
- not ready to order

Potential later Rev C/Rev D additions after bench validation:

- galvanically isolated RS-485,
- refined mechanical carrier,
- BLE support path if needed,
- optimized BOM/LCSC sourcing,
- production-focused layout cleanup.

## Rev D Compact Carrier

Rev D compact carrier geometry was started as a response to the oversized Rev C workflow board:

- PCB file created: `kicad/twn4_access_system/twn4_access_system_rev_d_compact_carrier.kicad_pcb`
- TWN4 50 mm x 35 mm envelope added as the primary mechanical reference.
- X2 is treated as the main mating connector.
- RPi gateway footprints were removed from this compact carrier variant and should become a separate board/schematic path.
- Preview exported: `manufacturing/rev_d/rev_d_compact_carrier_preview.pdf`

Current Rev D status:

- placement-only compact geometry pass with hard placement shorts cleared,
- not routed,
- DRC not clean because nets are still unrouted,
- not ready to order.

## Rev E Compact Carrier

Rev E is the next compact carrier iteration:

- PCB files:
  - `kicad/twn4_access_system/twn4_access_system_rev_e_compact_carrier.kicad_pcb`
  - `kicad/twn4_access_system/twn4_access_system_rev_e_compact_routed.kicad_pcb`
- Schematic copy:
  - `kicad/twn4_access_system/twn4_access_system_rev_e.kicad_sch`
- Smaller 3.50 mm Phoenix PT-1,5 style field connector footprints were used instead of the earlier 5.08 mm terminal blocks.
- Approximate board outline after cleanup: 102 mm x 72 mm.
- RPi gateway is intentionally separated from the compact TWN4 carrier.
- Routed through DSN/SES workflow and imported back into KiCad.
- Manufacturing draft files were exported under `manufacturing/rev_e`.

Current Rev E status:

- DRC clean: 0 violations, 0 unconnected pads, 0 footprint errors.
- Gerber, drill, BOM, CPL, and preview exports exist.
- Still not order-approved because buck layout, lock current paths, X2/standoff mechanics, and JLCPCB/LCSC BOM sourcing need manual review.

## Rev F Power Layout Audit

Rev F was created from the Rev E routed checkpoint as a power-layout audit branch.

- PCB file:
  - `kicad/twn4_access_system/twn4_access_system_rev_f_compact_power_cleanup.kicad_pcb`
- Schematic copy:
  - `kicad/twn4_access_system/twn4_access_system_rev_f.kicad_sch`
- Manufacturing draft outputs:
  - `manufacturing/rev_f`
- Report:
  - `reports/018_rev_f_power_layout_audit.md`

Current Rev F status:

- DRC clean: 0 violations, 0 unconnected pads, 0 footprint errors.
- Widening the existing autorouted power traces was tested and rejected because it produced clearance and shorting violations.
- Rev F is not order-approved. The next real PCB work is manual rerouting of buck and lock/relay power paths.

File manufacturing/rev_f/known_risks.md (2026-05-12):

# Rev F Known Risks

## Critical blockers

- Buck converter is still routed as an autorouter-derived layout.
- Lock/relay power routing has not been manually current-reviewed.
- Wider power traces cannot be applied safely without manual rerouting because the existing topology has tight clearances.

## Mechanical risks

- X2 position and height must be validated against a real TWN4 reader.
- Standoff height and mounting holes are not final.
- Board outline remains an engineering carrier outline.

## Electrical risks

- Real lock current is unknown.
- 3.50 mm field connector current rating must be checked against the selected lock and cable.
- Input protection ratings should be checked against expected installation surges.
- RS-485 bias/termination policy must be validated in the final bus topology.

## Manufacturing risks

- BOM is a KiCad export, not a sourced LCSC/JLCPCB assembly BOM.
- CPL must be reviewed in JLCPCB preview.
- Some connectors and the TWN4 mating connector may require manual assembly.

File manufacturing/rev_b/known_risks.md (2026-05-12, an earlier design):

# Rev B Known Risks

## Critical

- PCB layout does not exist yet, so hardware is not orderable.
- Exact TWN4 X2 mechanical alignment is not verified.
- TWN4 COM1 low-active polarity must be verified on a scope.

## High

- Lock current and lock type are unknown.
- Input transient environment is unknown.
- Final JLCPCB/LCSC part mapping is not done.

## Medium

- Galvanic isolation is deferred to Rev C unless field wiring demands it.
- RS-485 A/B naming may need correction after bench testing.
- Local symbol migration to a proper KiCad library is started but not complete in the active schematic.

## Mechanical TODO

- Exact reader pin coordinates.
- Connector height.
- Standoff height.
- Mounting hole coordinates.
- Reader body keep-out.

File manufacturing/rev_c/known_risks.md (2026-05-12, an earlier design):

# Rev C Known Risks

## Critical

- TWN4 connector mechanics are not validated.
- Autorouted PCB has not had manual senior layout review.

## High

- CPL coordinates come from automatic placement and need manual review.
- Board dimensions are service-preview dimensions, not final enclosure dimensions.
- Lock current path is routed but not width/thermal reviewed.
- Buck regulator route exists but is not manually optimized against datasheet layout guidance.
- RS-485 TVS/protection physical placement needs review.

## Medium

- Silkscreen has warning/overlap findings.
- BOM still needs final MPN/LCSC mapping.
- Some parts may require hand assembly.

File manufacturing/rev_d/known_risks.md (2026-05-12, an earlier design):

# Rev D Known Risks

- X2 mechanical alignment is based on documentation and must be physically checked against the real TWN4 reader.
- Connector mating height and standoff height are not finalized.
- 5.08 mm terminal blocks are probably too large for the final compact product.
- RPi gateway hardware is intentionally excluded from Rev D compact carrier.
- Autorouted buck power loop is not production-quality.
- Autorouted lock/relay power paths require current-width review.
- RS-485 polarity and OSDP firmware behavior require bench testing.
- BOM is not fully LCSC/JLCPCB sourced.
- Gerbers include extra layers and need filtering before upload.

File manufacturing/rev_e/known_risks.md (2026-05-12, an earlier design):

# Rev E Known Risks

## Mechanical

- X2 position and height must be validated on a real TWN4 reader.
- Standoff height and mounting hole positions are not final.
- Board outline is an engineering carrier outline, not final enclosure geometry.

## Power

- 12-48 V input concept is present, but buck layout must be manually reviewed.
- Switching loop geometry is not yet optimized.
- Input protection and TVS ratings should be checked against installation surge expectations.

## Lock and relay

- Real lock current is unknown.
- Copper width and connector current rating must be checked against the selected lock.
- Inductive protection should be confirmed for the final lock wiring topology.

## RS-485 / OSDP

- A/B polarity must be validated with the actual RPi gateway/control panel.
- Bias and termination policy must be confirmed for multi-reader bus topology.
- Galvanic isolation is not included in this first compact carrier pass.

## Manufacturing

- BOM is not yet a verified JLCPCB/LCSC assembly BOM.
- CPL exists but must be checked in JLCPCB preview.
- Some parts may need manual assembly.

## Documentation

- Rev E schematic was copied from the broader Rev B schematic. Compact carrier PCB intentionally excludes the RPi gateway. A later cleanup should split schematics by product board.

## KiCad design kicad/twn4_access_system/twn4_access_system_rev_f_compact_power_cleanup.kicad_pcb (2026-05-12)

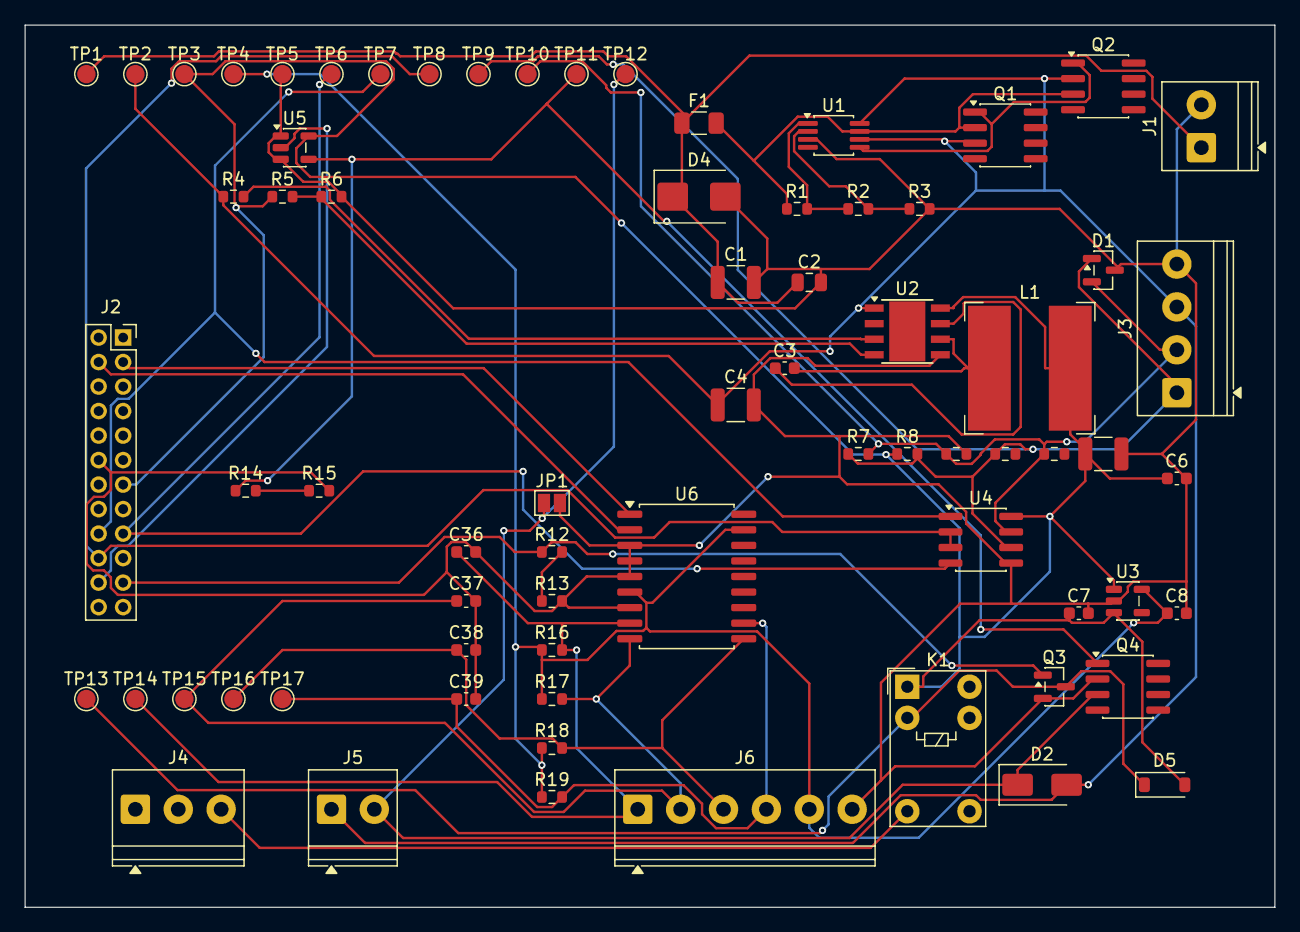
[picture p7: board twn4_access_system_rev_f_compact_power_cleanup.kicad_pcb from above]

Board: 2 copper layers, 102.0 x 72.0 mm, 72 parts (0 on the bottom side), 32 nets.

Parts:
C1: 4.7uF 100V X7R input bulk; C_1210_3225Metric
C2: 100nF 100V input HF; C_0805_2012Metric
C3: 100nF BST; C_0603_1608Metric
C4: 22uF 100V buck input; C_1210_3225Metric
C5: 47uF 10V buck output; C_1210_3225Metric
C6: 100nF 5V HF; C_0603_1608Metric
C7: 1uF 3V3 LDO in; C_0603_1608Metric
C8: 1uF 3V3 LDO out; C_0603_1608Metric
C36: 10nF DOOR_IN filter; C_0603_1608Metric
C37: 10nF REX_IN filter; C_0603_1608Metric
C38: 10nF TAMPER_IN filter; C_0603_1608Metric
C39: 10nF AUX_IN filter; C_0603_1608Metric
D1: SM712 RS-485 TVS; SOT-23
D2: Lock flyback diode/TVS placeholder; D_SMA
D4: SMBJ58A input TVS; D_SMB
D5: Relay flyback diode; D_SOD-123
F1: 1.5A 60V+ fuse/PTC; Fuse_1206_3216Metric
J1: VIN 12-48V IN; TerminalBlock_Phoenix_PT-1,5-2-3.5-H_1x02_P3.50mm_Horizontal
J2: TWN4 MultiTech 3 BLE X2 socket; PinSocket_2x12_P2.00mm_Vertical
J3: RS-485 OUT A/B/+VIN/GND; TerminalBlock_Phoenix_PT-1,5-4-3.5-H_1x04_P3.50mm_Horizontal
J4: Relay contact COM/NC/NO; TerminalBlock_Phoenix_PT-1,5-3-3.5-H_1x03_P3.50mm_Horizontal
J5: LOCK OUT +VIN/SW-; TerminalBlock_Phoenix_PT-1,5-2-3.5-H_1x02_P3.50mm_Horizontal
J6: DOOR/REX/TAMPER/AUX inputs; TerminalBlock_Phoenix_PT-1,5-6-3.5-H_1x06_P3.50mm_Horizontal
JP1: LOCK SERVICE LINK; SolderJumper-2_P1.3mm_Open_Pad1.0x1.5mm
K1: Dry relay contact NO/NC/COM; Relay_SPDT_Omron_G5V-1
L1: 47uH shielded inductor; L_Bourns-SRN1060
Q1: Reverse/surge FET A 100V; SOIC-8_3.9x4.9mm_P1.27mm
Q2: Reverse/surge FET B 100V; SOIC-8_3.9x4.9mm_P1.27mm
Q3: Relay low-side driver; SOT-23
Q4: Lock low-side MOSFET 100V; SOIC-8_3.9x4.9mm_P1.27mm
R1: 1M UV/OV top placeholder; R_0603_1608Metric
R2: 100k UV/OV mid placeholder; R_0603_1608Metric
R3: 27k UV/OV bottom placeholder; R_0603_1608Metric
R4: 200k LM5164 RON; R_0603_1608Metric
R5: 604k 5V FB top; R_0603_1608Metric
R6: 100k 5V FB bottom; R_0603_1608Metric
R7: 120R RS485 TERM DNP/JMP; R_0603_1608Metric
R8: 680R RS485 bias pullup DNP/JMP; R_0603_1608Metric
R9: 680R RS485 bias pulldown DNP/JMP; R_0603_1608Metric
R10: 22R RS485 A series option; R_0603_1608Metric
R11: 22R RS485 B series option; R_0603_1608Metric
R12: 100R relay gate; R_0603_1608Metric
R13: 100k relay gate pulldown; R_0603_1608Metric
R14: 100R lock gate; R_0603_1608Metric
R15: 100k lock gate pulldown; R_0603_1608Metric
R16: 10k DOOR_IN pullup; R_0603_1608Metric
R17: 10k REX_IN pullup; R_0603_1608Metric
R18: 10k TAMPER_IN pullup; R_0603_1608Metric
R19: 10k AUX_IN pullup; R_0603_1608Metric
TP1: VIN_IN; TestPoint_Pad_D1.5mm
TP2: VIN_PROT; TestPoint_Pad_D1.5mm
TP3: +5V; TestPoint_Pad_D1.5mm
TP4: +3V3; TestPoint_Pad_D1.5mm
TP5: GND; TestPoint_Pad_D1.5mm
TP6: COM1_TX; TestPoint_Pad_D1.5mm
TP7: COM1_RX; TestPoint_Pad_D1.5mm
TP8: GPIO4_RS485_DIR; TestPoint_Pad_D1.5mm
TP9: RS485_A; TestPoint_Pad_D1.5mm
TP10: RS485_B; TestPoint_Pad_D1.5mm
TP11: LOCK_GATE_5V; TestPoint_Pad_D1.5mm
TP12: LOCK_SW_LOW; TestPoint_Pad_D1.5mm
TP13: RELAY_COIL_LOW; TestPoint_Pad_D1.5mm
TP14: DOOR_IN; TestPoint_Pad_D1.5mm
TP15: REX_IN; TestPoint_Pad_D1.5mm
TP16: TAMPER_IN; TestPoint_Pad_D1.5mm
TP17: AUX_IN; TestPoint_Pad_D1.5mm
U1: LTC4367 surge/OV/UV protector; MSOP-8_3x3mm_P0.65mm
U2: LM5164 12-48V to 5V buck; Texas_HSOP-8-1EP_3.9x4.9mm_P1.27mm
U3: TLV75533 3.3V local rail; SOT-23-5
U4: THVD1450 reader RS-485 transceiver; SOIC-8_3.9x4.9mm_P1.27mm
U5: 5V gate buffer for lock FET; SOT-23-5
U6: MCP23008 door input expander; SOIC-18W_7.5x11.6mm_P1.27mm

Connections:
+3V3: C8.1, J6.5, R16.1, R17.1, R18.1, R19.1, TP4.1, U3.5, U6.6, U6.17
+5V: C5.1, C6.1, C7.1, D5.2, J2.13, K1.1, L1.2, R5.1, R8.1, TP3.1, U2.8, U3.1, U3.3, U4.8, U5.5
AUX_IN: C39.1, J6.4, R19.2, TP17.1, U6.11
BST_NODE: C3.1, U2.7
COM1_RX: J2.18, TP7.1, U4.1
COM1_TX: J2.17, TP6.1, U4.4
DOOR_IN: C36.1, J6.1, R16.2, TP14.1, U6.8
FB_5V: R5.2, R6.1, U2.4
GND: C1.2, C2.2, C4.2, C5.2, C6.2, C7.2, C8.2, C36.2, C37.2, C38.2, C39.2, D1.3, D4.2, J1.2, J2.12, J3.4, J6.6, JP1.2, Q3.2, Q4.2, R3.2, R6.2, R9.2, R13.2, R15.2, TP5.1, U1.3, U2.5, U3.2, U4.5, U5.1, U5.3, U6.3, U6.4, U6.5, U6.7
GPIO4_RS485_DIR: J2.20, TP8.1, U4.2, U4.3
GPIO5_RELAY: J2.21, Q3.1, R12.1
GPIO6_LOCK: J2.22, U5.2
I2C_SCL: J2.3, U6.1
I2C_SDA: J2.4, U6.2
LOCK_GATE_5V: Q4.1, R14.1, TP11.1, U5.4
LOCK_GATE_DRV: R14.2, R15.1
LOCK_SW_LOW: D2.1, J5.2, JP1.1, Q4.3, TP12.1
OV_NODE: R2.2, R3.1, U1.2
PROT_GATE: Q1.1, Q2.1, U1.5
RELAY_COIL_LOW: D5.1, K1.2, Q3.3, TP13.1
RELAY_GATE: R12.2, R13.1
RELAY_NO: J4.3, K1.5
REX_IN: C37.1, J6.2, R17.2, TP15.1, U6.9
RON_NODE: R4.2, U2.3
RS485_A: D1.1, J3.1, R7.1, R8.2, R10.1, TP9.1, U4.6
RS485_B: D1.2, J3.2, R7.2, R9.1, R11.1, TP10.1, U4.7
SW_NODE: C3.2, L1.1, U2.6
TAMPER_IN: C38.1, J6.3, R18.2, TP16.1, U6.10
UV_NODE: R1.2, R2.1, U1.1
VIN_FUSED: F1.2, Q1.2, Q2.3, R1.1, U1.7
VIN_IN: C1.1, C2.1, D4.1, F1.1, J1.1, TP1.1
VIN_PROT: C4.1, D2.2, J3.3, J5.1, Q1.3, Q2.2, R4.1, TP2.1, U1.6, U1.8, U2.1

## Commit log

2026-05-06 Initial TWN4 carrier and RS-485 gateway concept
    [twn4_access_system.kicad_sch]
2026-05-12 rev-e: add compact carrier prototype package
    [bom_rev_b.csv, rev_b_assembly_classification.csv, rev_b_kicad_bom.csv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]
2026-05-12 rev-f: add power layout audit checkpoint
    [rev_f_kicad_bom.csv, twn4_access_system_rev_f.kicad_sch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]
